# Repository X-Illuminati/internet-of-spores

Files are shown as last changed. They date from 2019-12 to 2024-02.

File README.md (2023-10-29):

# Internet of Spores
IOT Sensor Platform for ESP8266 Arduino
Specifically targeting Lolin D1 Mini.  
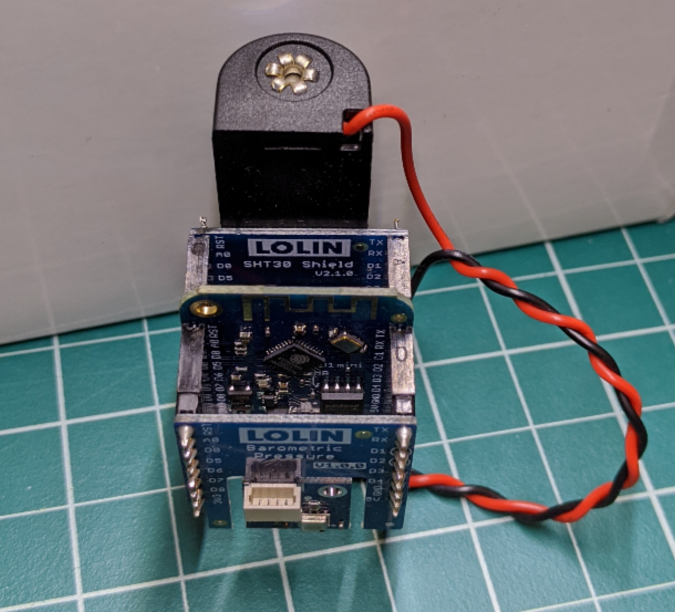
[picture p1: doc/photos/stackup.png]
D1 mini board stackup
  
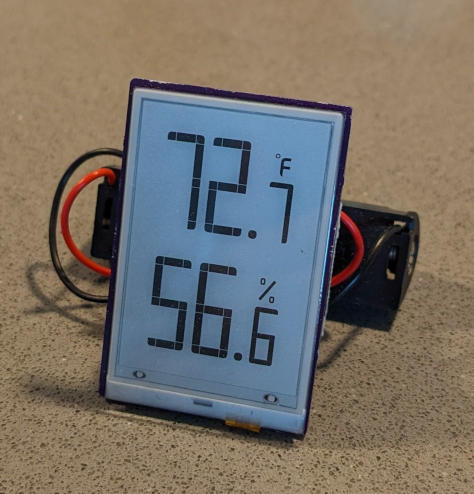
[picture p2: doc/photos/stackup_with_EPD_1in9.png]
Waveshare 1.9 in segmented E-Paper Display
  
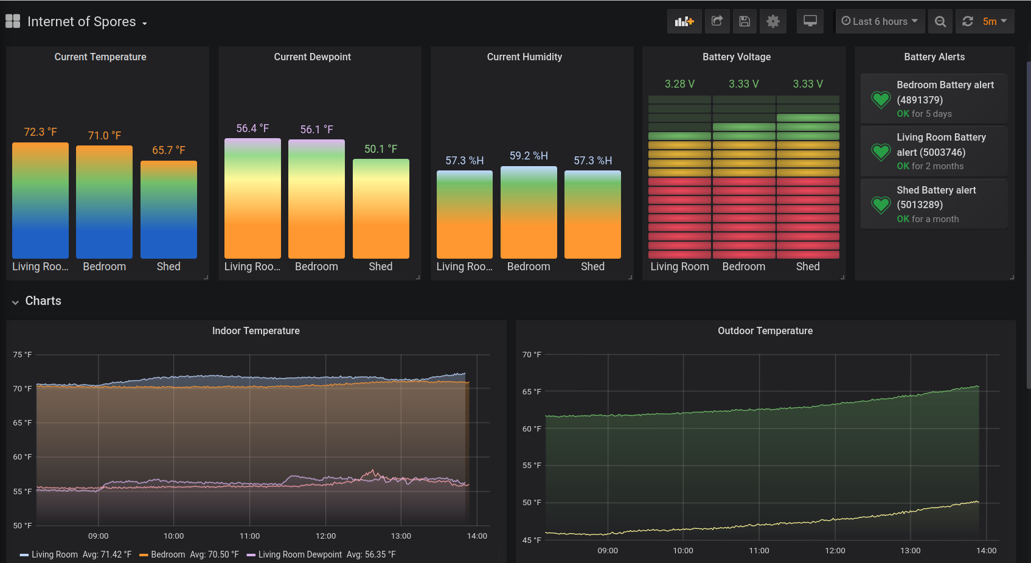
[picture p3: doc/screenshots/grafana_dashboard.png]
Grafana Dashboard


## Supported Sensors
* Temperature
  * SHT30
  * HP303B
* Relative Humidity
  * SHT30
* Barometric Pressure
  * HP303B
* Dust/Particle
  * PPD42NS

## Documentation (work-in-progress)
* [Developer Documentation](doc/README.md)
* [User Guide](doc/user_guide.md)

## Toolchain Setup and Library Dependencies

### ESP8266 Arduino
The ESP8266 Arduino toolchain is used to compile the code and provide basic
networking and multitasking services.
Project github: https://github.com/esp8266/Arduino

The toolchain can be installed via the Arduino board manager.
Instructions for this can be found [in their readme](https://github.com/esp8266/Arduino/blob/master/README.md).

#### Supported Version
I have thoroughly tested version 2.5.2 and 2.6.3. The latest version 3.0.2
required some changes to the code and I have not done the same level of testing
on these changes.
See the details below related to configurations/setting differences needed for
each version.

#### Board Setup
Most board settings can be left at their defaults.
* Don't forget to select your board type and COM port
* Need to configure some flash for SPIFFS
  * v2.5.2: select Flash Size "4M (1M SPIFFS)"
  * v2.6.3: select Flash Size "4MB (FS:1MB OTA:~1019KB)"
  * v3.0.2: select Flash Size "4MB (FS:1MB OTA:~1019KB)"

### WiFi Manager
There is a library dependency on WiFiManager by tzapu.
Project github: https://github.com/tzapu/WiFiManager

This can be installed via the library manager.
Please select a compatible version:
* v2.5.2: use WiFiManager version 0.14.0
* v2.6.3: use WiFiManager version 0.15.0-beta
* v3.0.2: use WiFiManager version 0.16.0

### Lolin HP303B Driver
There is a library dependency on the Lolin HP303B driver.
Project github: https://github.com/wemos/LOLIN_HP303B_Library

This is not available in the library manager so it will have to be installed
manually. Clone or download the library from the link above. Installation
instructions can be found [in this guide](https://www.arduino.cc/en/Guide/Libraries).

Tested version from commit 4deb5f.

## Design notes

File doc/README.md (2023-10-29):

# Documentation

## Table of Contents
* [System Architecture](system_architecture.md)
* Sensor Design
  * [Sensor Hardware](sensor_hardware.md)
  * [Sensor Software Architecture](software_architecture.md)
  * [Sensor Software Design](software_design_detail.md)
* Server Design
  * [Server Software Architecture](server_architecture.md)
  * [Server Software Design](server_design_detail.md)
* [User Guide](user_guide.md)

## Folder Structure
* [Top Level](../)
  * [README](../README.md)
  * [LICENSE](../LICENSE)
  * [internet_of_spores.ino](../internet_of_spores.ino) - Arduino Project File
  * C++ Modules for the Sensor Software
  * [flash.sh](../flash.sh) - Script to help program the ESP8266 over a serial port
  * [monitor.sh](../monitor.sh) - Script to monitor the ESP8266 serial port for debugging
  * [doc/](../doc/) - Documentation for the project
    * [README.md](README.md) - Documentation overview
    * [user_guide.md](user_guide.md) - Usage instructions
    * [drawio/](drawio/) - Draw.io Diagram Files
    * [photos/](photos/)
    * [renders/](renders/)
    * [screenshots/](screenshots/)
  * [firmware/](../firmware/) - Firmware images for the sensor nodes
    * ...-iotsp-tethered.bin - Firmware image for USB powered sensor nodes
    * ...-iotsp-battery.bin - Firmware image for battery-powered sensor nodes
    * ...-vcc-calibration.bin - Firmware image that rapidly reports battery level for calibration purposes
  * [kicad/](../kicad/) - KiCad projects
    * [EPD_1in9/](../kicad/EPD_1in9/) - KiCad project for the E-Paper Display Board
      * [EPD_1in9_schematic.pdf](../kicad/EPD_1in9/EPD_1in9_schematic.pdf) - PDF version of the schematic
  * [node-red/](../node-red/) - Node-Red flows and helper scripts
  * [openscad/](../openscad/) - OpenSCAD projects
    * [EPD_1in9.scad](../openscad/EPD_1in9.scad) - 3D Model for the Waveshare 1.9" E-Paper Display

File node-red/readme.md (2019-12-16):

# Node-RED flows.json
The node-red flows.json implements the measurement data collection and firmware
update procedure.

## Dependencies
The node-red flows are tested on v1.0.2 of Node-RED running on Node.js v10.15.2.
The node-red flows write data into an influxdb database. This has been tested
with v1.6.4 of influxdb-server.
Influxdb needs to be set up with a database called "home" and a measurement
called "internet_of_spores". The flows will look for this on localhost:8086.

There are some dependencies on community-contributed node programs.
These are available through the node-red palette manager and more details can
be found on [nodered.org](https://nodered.org).
The version numbers are the versions I have tested. Presumably newer versions
will also work.

* [node-red-contrib-readdir v1.0.1](https://flows.nodered.org/node/node-red-contrib-readdir)
* [node-red-contrib-md5 v1.0.4](https://flows.nodered.org/node/node-red-contrib-md5)
* [node-red-contrib-influxdb v0.4.0](https://flows.nodered.org/node/node-red-contrib-influxdb)

# Node-Red systemd unit file
The node-red.service is a systemd unit file that can be used to create a
systemd service to start and run the flows. It is compatible with being run as
a systemd user-service if installed in ~/.local/share/systemd/user/.

```shell
systemctl --user start node-red.service
systemctl --user restart node-red.service
systemctl --user stop node-red.service
systemctl --user status node-red.service
```

## State of Health Monitor
The soh-monitor.sh script will monitor the journal output of node-red and
expect periodic watch-dog statements. If node-red locks-up, the script will
restart it after a few minutes using systemctl.

The soh-monitor also has a systemd unit file, "node-red-soh.service". It can
be installed and started in the same way as node-red.service. Since it depends
on node-red.service, you only need to start the node-red-soh service and the
node-red service will automatically be started.

```shell
systemctl --user start node-red-soh.service
systemctl --user stop node-red-soh.service
systemctl --user status node-red-soh.service
```

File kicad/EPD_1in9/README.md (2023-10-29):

# EPD_1in9 KiCad

## KiCad 3D-view Render
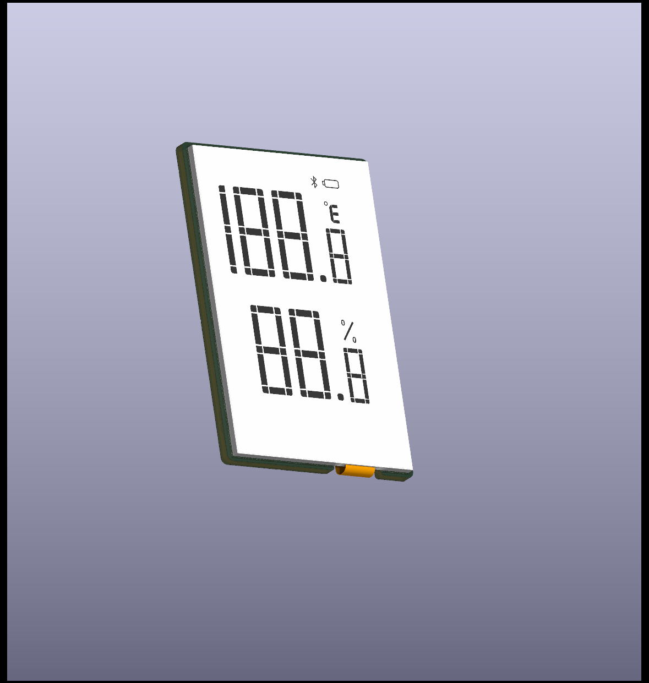
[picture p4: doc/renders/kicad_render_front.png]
KiCad 3D-view Render Front

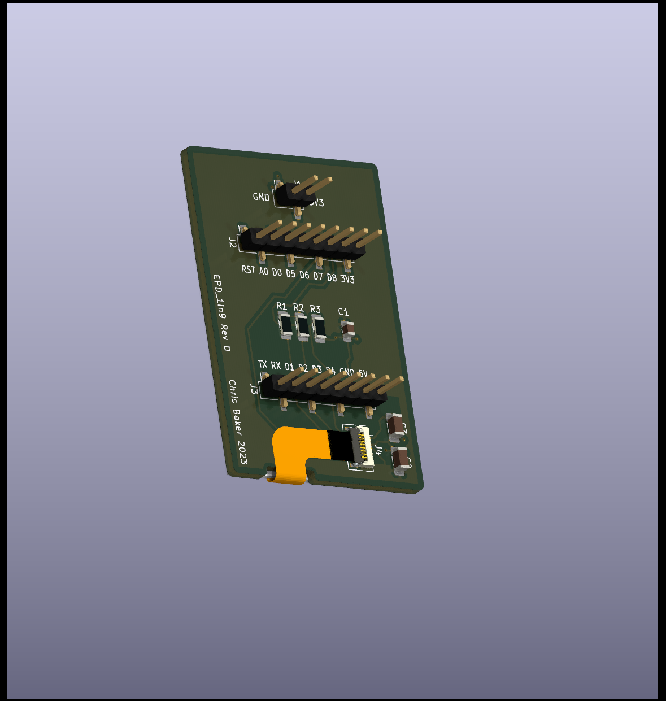
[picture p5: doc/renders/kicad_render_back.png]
KiCad 3D-view Render Back


## Schematic PDF
[EPD_1in9 Schematic](EPD_1in9_schematic.pdf)

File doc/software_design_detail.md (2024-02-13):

# Sensor Software Design
This outline is currently a work-in-progress.

## Table of Contents

* [Module Overview](#module-overview)
* [Project Configuration](#project-configuration)
* [Module Description](#module-description)
  - [Main Module](#main-module)
  - [RTC Mem](#rtc-mem)
  - [Persistent Storage](#persistent-storage)
  - [Connectivity](#connectivity)
  - [Sensors](#sensors)
  - [SHT30](#sht30)
  - [PPD42 Pulse Driver](#ppd42-pulse-driver)
  - [E-Paper Display Driver](#e-paper-display-driver)
* [Debugging and Unit Testing](#debugging-and-unit-testing)
  - [Development Mode](#development-mode)
  - [VCC Cal Mode](#vcc-cal-mode)
* [Future Improvements](#future-improvements)

---

## Module Overview

Refer to the [sensor software architecture](software_architecture.md) for an
overview of the component decomposition and logical architecture of the product.
The block diagram, repeated here, can serve as a high-level reference:  
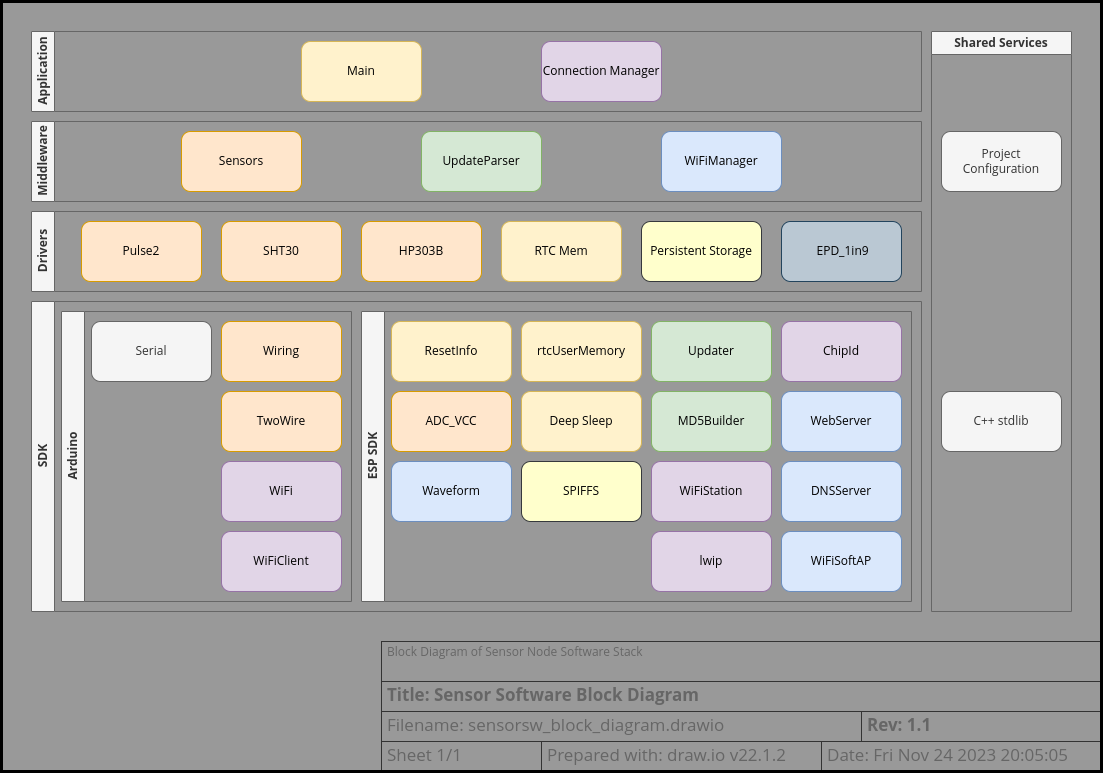
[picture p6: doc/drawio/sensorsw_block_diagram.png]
Software Stack


In this overview, the correspondence between the logical architecture and the
individual software modules is indicated by the dashed-line regions.  
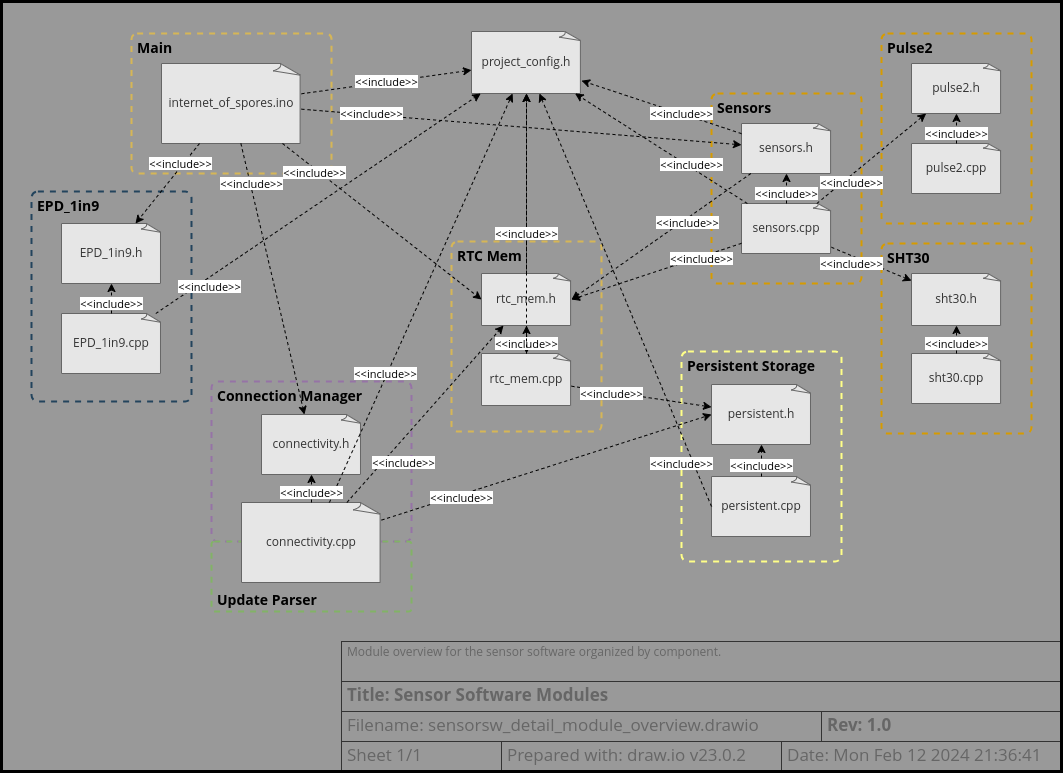
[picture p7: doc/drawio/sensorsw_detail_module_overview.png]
Module Overview
  
Later in the document, a detailed discussion of each module will be provided.

A couple of points are immediately apparent from examination of this diagram:
* project_config.h is a centralized locus of configuration information
* The RTC Mem component is more highly coupled than it should be
* connectivity.cpp is implementing two logical components

The later two points will be addressed in the
[future improvements section](#future-improvements).

---

## Project Configuration
- Describe configuration options, static modes, build ID
- Describe build system/toolchain

---

## Module Description
(configuration options, flow charts, classes, fault tolerance, notes, dependencies)
### Main Module
### RTC Mem
### Persistent Storage
### Connectivity
### Sensors
### SHT30
### PPD42 Pulse Driver
### E-Paper Display Driver

---

## Debugging and Unit Testing
### Development Mode
### VCC Cal Mode

---

## Future Improvements

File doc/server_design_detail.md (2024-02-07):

# Server Software Design

## Table of Contents

* [Module Overview](#module-overview)
* [Project Configuration](#project-configuration)
* [Module Description](#module-description)
  - [Node-RED Flows](#node-red-flows)
    + [Main Entry](#main-entry)
    + [Handle Sensor Readings](#handle-sensor-readings)
    + [Update Firmware](#update-firmware)
    + [Update Config](#update-config)
    + [State of Health](#state-of-health)
  - [Node-RED SOH Monitor](#node-red-soh-monitor)
    + [script_main](#script_main)
    + [monitor](#monitor)
    + [Signal Traps](#signal-traps)
* [Debugging and Unit Testing](#debugging-and-unit-testing)
  - [Debugging Node-RED](#debugging-node-red)
  - [Debugging Node-RED SOH Monitor](#debugging-node-red-soh-monitor)
* [Future Improvements](#future-improvements)

---

## Module Overview

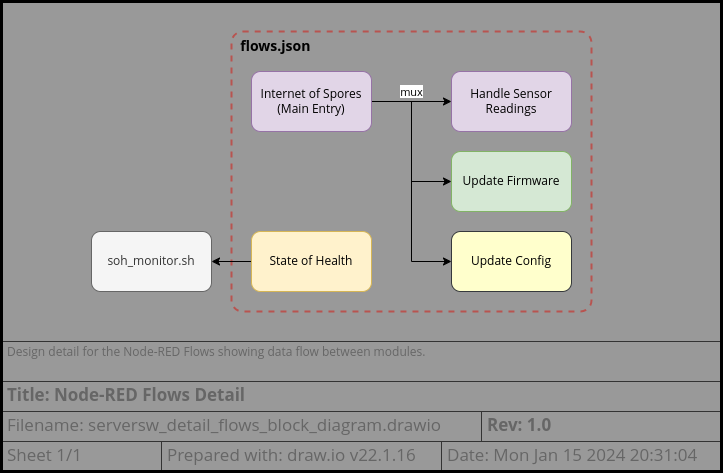
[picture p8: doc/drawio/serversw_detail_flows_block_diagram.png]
Module Data Flow Diagram
  
The server software components are split into [Node-RED Flows](#node-red-flows)
and the [SOH monitor](#node-red-soh-monitor). The flows.json includes several
sub-flows (arranged on different tabs in the UI).  
Based on the command in the incoming packet, the [Main Entry](#main-entry)
handler will hand it off to the relevant sub-flow. The
[State of Health](#state-of-health) sub-flow executes periodically and is
monitored by the external [SOH Monitor](#node-red-soh-monitor) utility.

---

## Project Configuration

The content of this component are all interpreted scripts and no compilation
step is needed. See the [software architecture](server_architecture.md) for more
details.

Launching of the Node-RED server and SOH Monitor is performed at startup by
[systemd unit files](https://www.freedesktop.org/software/systemd/man/systemd.unit.html).
To some extent these are configurable, but the
[soh-monitor.sh](../node-red/soh-monitor.sh) script is currently expecting the
units to be run under the "user" service manager. This behavior should be made
more configurable. Likewise, the script expects to be communicating with
systemctl and journalctl. In order to support other init systems, these commands
should be made more easily configurable.

For reference the unit files are:
* [node-red.service](../node-red/node-red.service) - starts the Node-RED server
* [node-red-soh.service](../node-red/node-red-soh.service) - starts the SOH
  monitor script

---

## Module Description

### Node-RED Flows

The flows are found in [flows.json](../node-red/flows.json) and are split into
the following tabs:
+ [Main Entry](#main-entry)
+ [Handle Sensor Readings](#handle-sensor-readings)
+ [Update Firmware](#update-firmware)
+ [Update Config](#update-config)
+ [State of Health](#state-of-health)

#### Main Entry

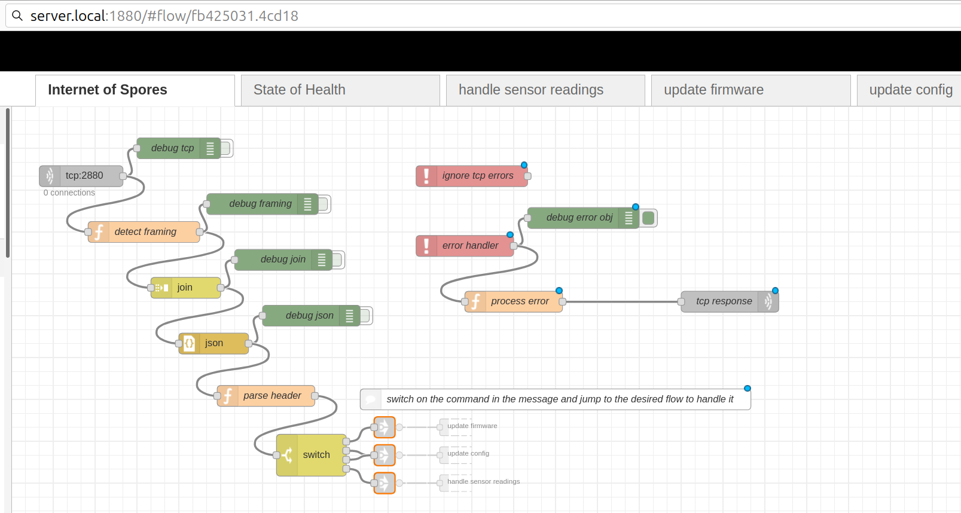
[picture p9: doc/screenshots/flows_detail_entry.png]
Flow Screenshot
  
The main flows listen on TCP port 2880 for incoming connections, collect
together fragmented packets, parse the packet as json, filter out the header
fields, and then pass the message on to the appropriate sub-flow based on the
command field.

The function nodes are relatively straightforward:
* "detect framing" looks for a null terminator in order to set the msg.complete
  flag
* "parse header" simply pulls out header fields from msg.payload and places them
  directly in the msg object
  - version
  - timestamp
  - node
  - firmware
* "process error" provides a TCP response of "error\0" for any error (except
  errors that it triggered with its own response)

The switch node works in the following way:
* If command == "update", transfers msg to the
  [update firmware sub-flow](#update-firmware)
* If command == "get_config" or "delete_config", transfers msg to the 
  [update config sub-flow](#update-config)
* If command is null, transfers msg to the
  [handle sensor readings sub-flow](#handle-sensor-readings)

#### Handle Sensor Readings

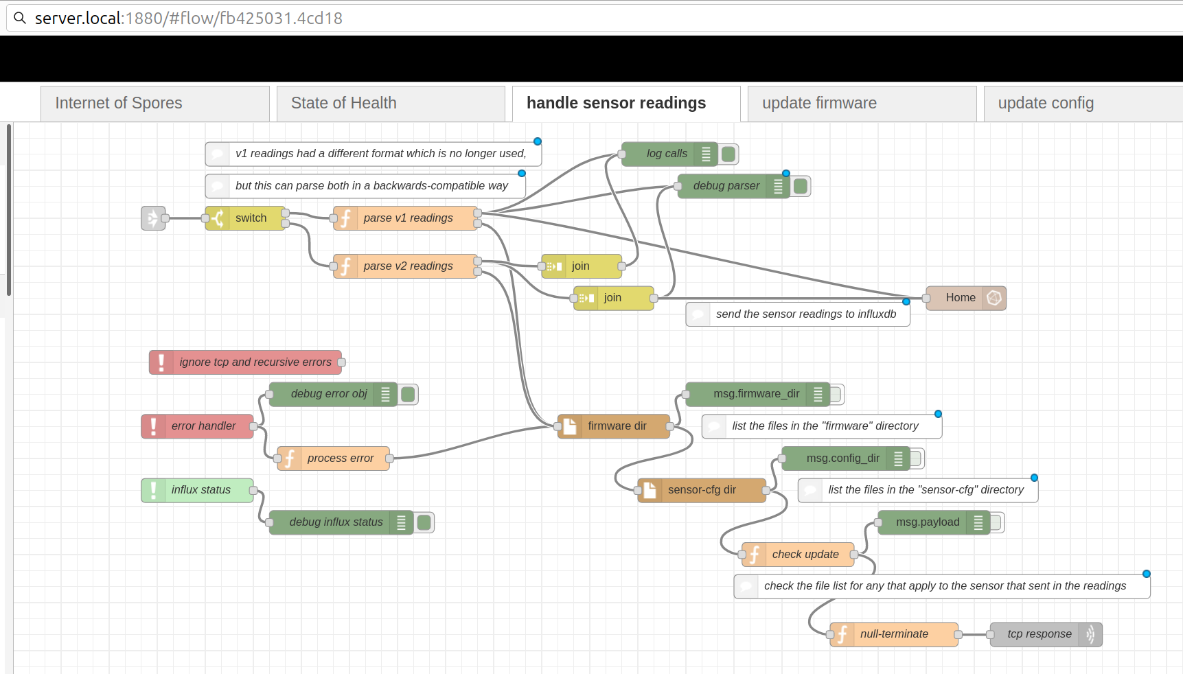
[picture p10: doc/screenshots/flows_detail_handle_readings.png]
Flow Screenshot


> 🪧 Note: this flow depends on the additional plugin modules:
> * [node-red-contrib-influxdb](https://flows.nodered.org/node/node-red-contrib-influxdb)
> * [node-red-contrib-readdir](https://flows.nodered.org/node/node-red-contrib-readdir)

When the msg is transferred to this sub-flow, it is first parsed to pull out the
sensor measurements. These measurements are then joined into a batch update to
be provided to the influxdb node.  
After each measurement is parsed, the response is generated - normally "OK". If
firmware updates or configuration updates are available, these flags will be
appended to the response.

The "influx status" node simply monitors status of the influxdb node and logs it
in the debug window.

**parse v2 readings**

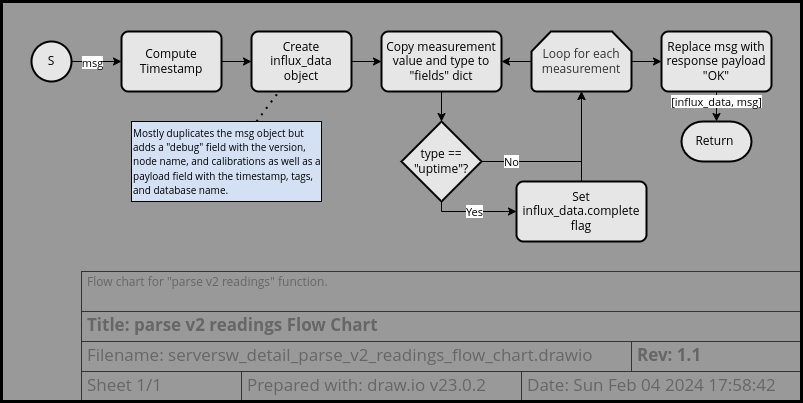
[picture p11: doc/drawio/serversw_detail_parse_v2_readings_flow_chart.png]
parse v2 readings flow chart


**check update**

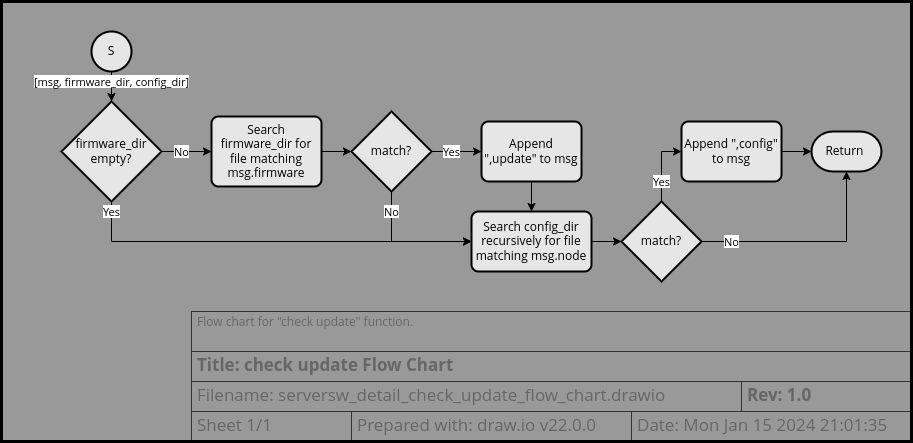
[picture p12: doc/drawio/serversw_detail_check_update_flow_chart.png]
check update flow chart


This function takes additionally as input msg.firmware_dir and msg.config_dir
which are provided by the preceding directory nodes.  These nodes can be
configured to modify the location of the respective firmware and sensor-cfg
directories, though it is probably easier to create softlinks in your Node-RED
runtime directory.

**null-terminate**

This function simply appends a "\0" character to the end of the response
message.

**process error**

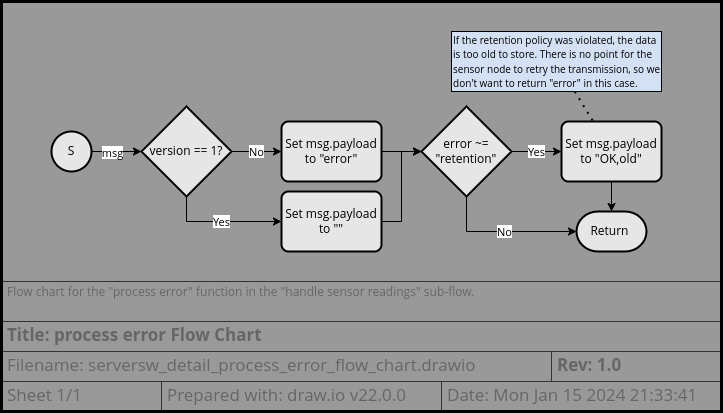
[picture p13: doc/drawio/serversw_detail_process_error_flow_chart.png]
process error flow chart


As on the main tab, the "process error" function returns a basic error response
to the sensor node in case any error occurs. Likewise, it ignores errors
generated by the "tcp response" node as these would likely generate further
errors as we attempt to send the error response recursively.

The difference from the main tab is that this function also handles errors from
the influx node and we want to handle "retention" errors as though they were
successful.  
The retention error indicates that InfluxDB received the measurement correctly,
but isn't storing it because it violates the retention policy. Generally, this
means that the timestamp is too old. In this case, there is no point for the
sensor node to retransmit the measurement, so we send an "OK,old" response.

#### Update Firmware

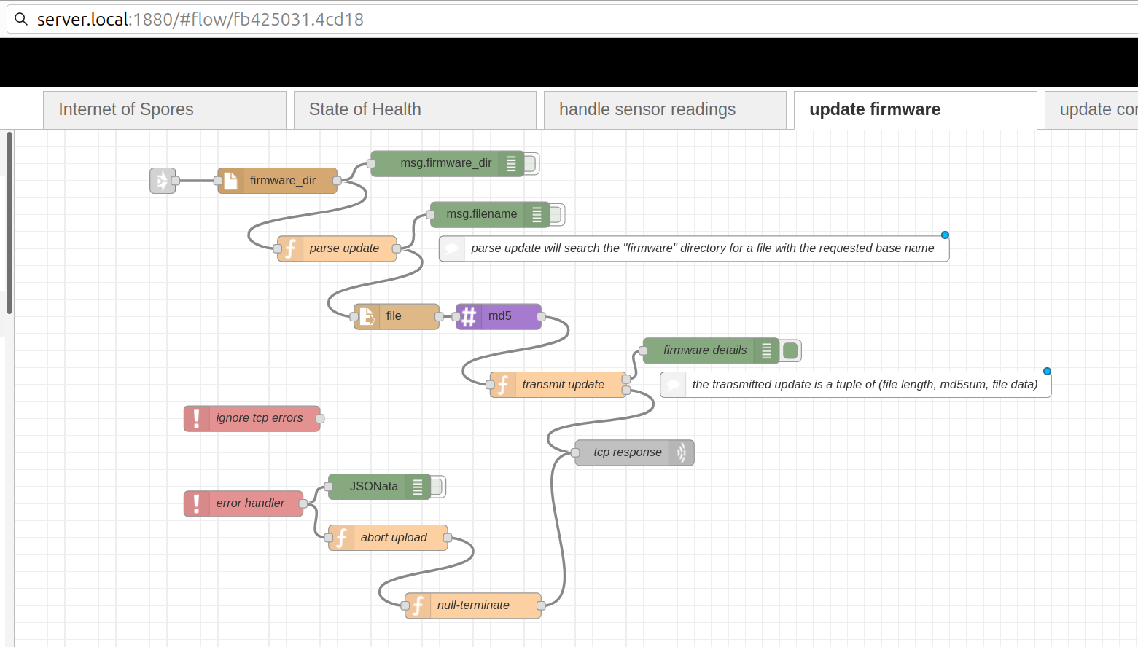
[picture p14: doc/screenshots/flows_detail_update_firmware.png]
Flow Screenshot


> 🪧 Note: this flow depends on the additional plugin modules:
> * [node-red-contrib-readdir](https://flows.nodered.org/node/node-red-contrib-readdir)
> * [node-red-contrib-md5](https://flows.nodered.org/node/node-red-contrib-md5)

When the msg is transferred to this sub-flow, the filename is extracted from the
payload argument and used to find the matching firmware image in the "firmware"
directory.  
If the image file is found, its md5 hash will be calculated and the update
package (length, md5, data) transmitted in the response.

**parse update**

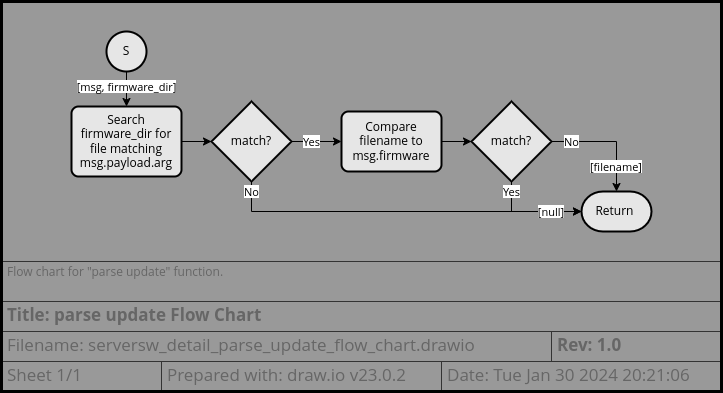
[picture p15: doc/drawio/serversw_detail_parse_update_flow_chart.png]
parse update flow chart


This function searches the list of files provided by the "firmware_dir" node
to find any that match the filename provided.  
As an extra check, it will ignore any firmware file that already matches the
firmware "fingerprint" reported by the sensor node as there is no point sending
an update file if the sensor is already running that version of software.

**transmit update**

This function crafts a response octet-string by concatenating the metadata and
content of the file:
* file length
* "\n"
* md5sum
* "\n"
* file data

> 🪧 Note: a final "\n" or "\0" is not included in this message as the file data
> will be processed by the ESP SDK firmware update functionality which expects
> a simple IO Stream with the file data only.  
> Additional framing would disturb the md5 checksum calculation.

**process error**

This function provides a TCP response of "0\n" for any error (except errors that
it triggered with its own response). 

**null-terminate**

This function simply appends a "\0" character to the end of the response
message.

#### Update Config

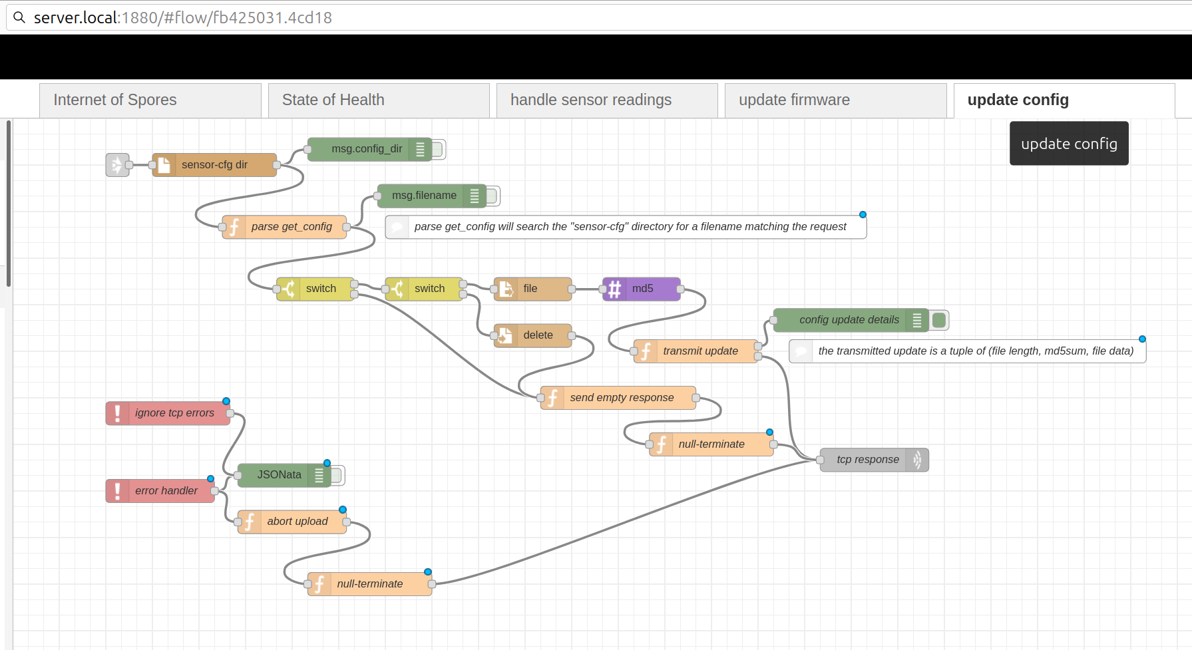
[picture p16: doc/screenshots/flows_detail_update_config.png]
Flow Screenshot


> 🪧 Note: this flow depends on the additional plugin modules:
> * [node-red-contrib-readdir](https://flows.nodered.org/node/node-red-contrib-readdir)
> * [node-red-contrib-md5](https://flows.nodered.org/node/node-red-contrib-md5)

When the msg is transferred to this sub-flow, the filename is extracted from the
payload argument and used to find the matching configuration file in the
"sensor-cfg" directory.  
Depending on whether the command is "get_config" or "delete_config", the file
will be returned to the sensor node or deleted, respectively.

**parse get_config**

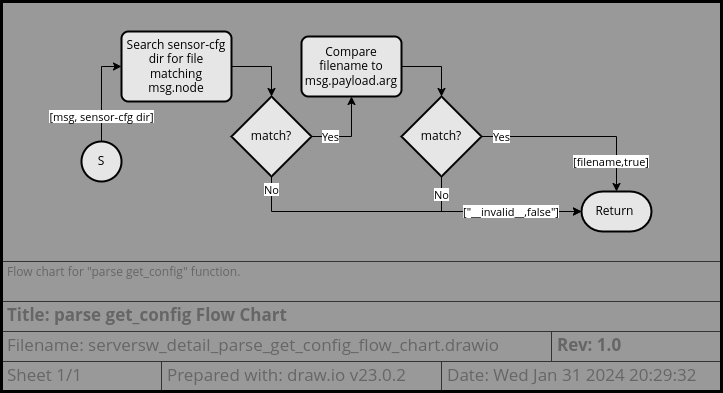
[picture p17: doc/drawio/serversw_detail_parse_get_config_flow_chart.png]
parse update flow chart


This function searches the list of files provided by the "firmware-cfg dir" node
to find any that match the node name and filename provided. For example, the
configuration update files might be in organized in subdirectories by node name
(sensor-cfg/node_name/cfg_file), but other schemes are possible
(sensor-cfg/node_name-cfg_file).

**transmit update**

This function crafts a response octet-string by concatenating the metadata and
content of the file:
* file length
* "\n"
* md5sum
* "\n"
* file data

**send empty response**

This function provides a TCP response of "\n" if no matching file was found.

**abort upload**

This function provides a TCP response of "0\n" for any error (except errors that
it triggered with its own response). 

**null-terminate**

This function simply appends a "\0" character to the end of the response
message.

#### State of Health

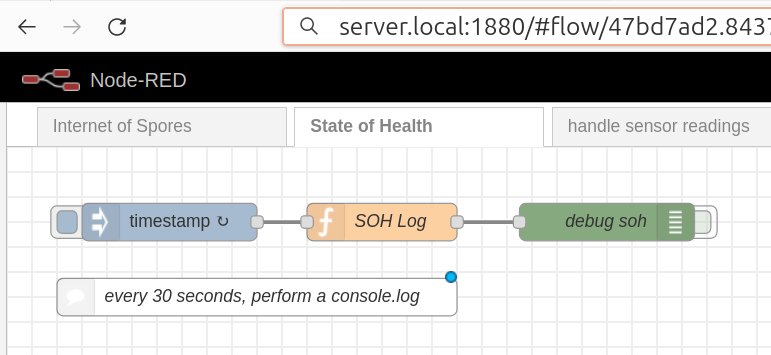
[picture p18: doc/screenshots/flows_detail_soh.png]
Flow Screenshot


This flow executes asynchronously every 30 seconds (starting 3 seconds after the
flows are started).

**SOH Log**

This function performs a console.log of the string "@SOH report@" + the
timestamp.

### Node-red SOH Monitor

The SOH Monitor script is located in
[soh-monitor.sh](../node-red/soh-monitor.sh).

The main configuration interface is via command line parameters.
These are optional:
* If 1 parameter is supplied, it is: timeout
* If 2 parameters are supplied: timeout, action count
* If 3 parameters are supplied: timeout, action count, max errors

The defaults for these (along with the additional RELOAD_TIME parameter) can be
adjusted at the top of the script.

This script depends on bash -- simpler bourne shells will probably fail in an
unexpected way. Additionally, it depends on systemd utilities: systemctl and
journalctl.

> 🪧 Note: The script expects Node-RED to be running under the "user" service
> manager rather than the "system" service manager. This should probably be
> made more configurable or allow some level of auto-detection.

There are 3 basic parts to the script:
* [Signal Traps](#signal-traps)
* [script_main](#script_main)
* [monitor](#monitor)

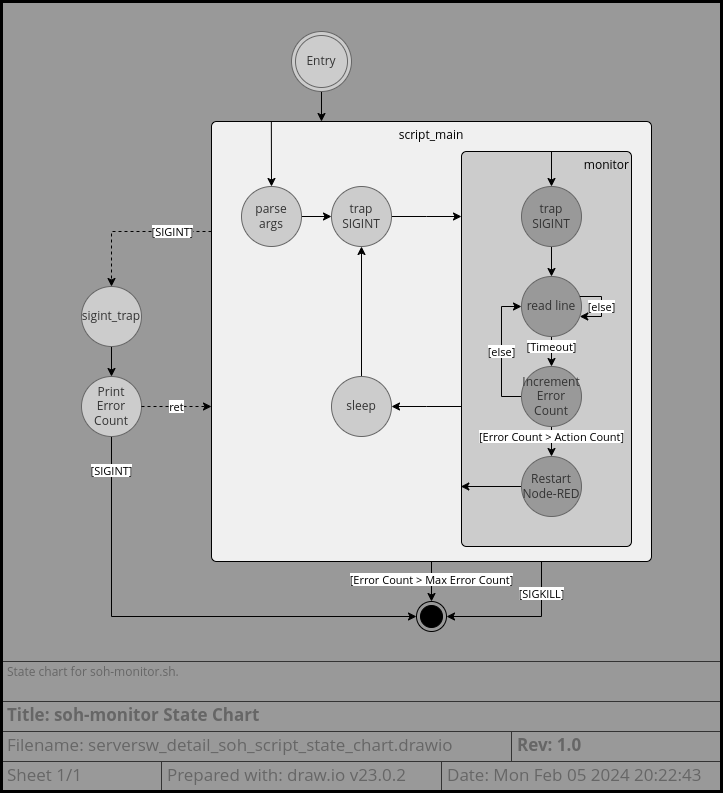
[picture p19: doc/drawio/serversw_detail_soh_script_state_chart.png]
soh-monitor State Chart


#### script_main

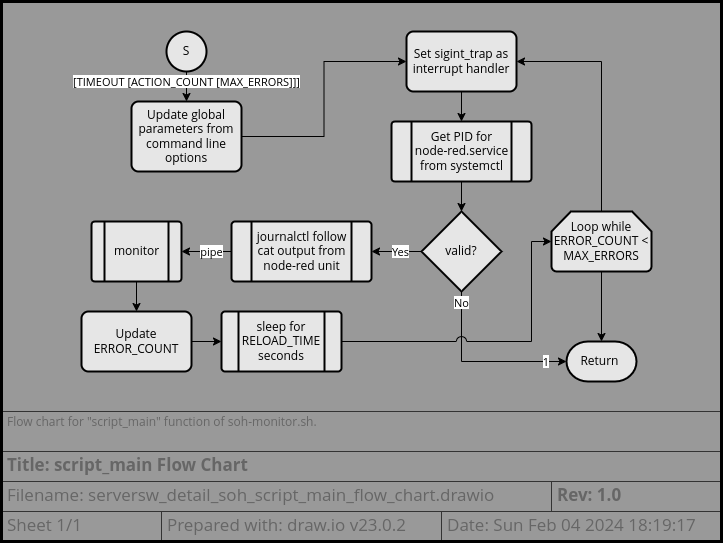
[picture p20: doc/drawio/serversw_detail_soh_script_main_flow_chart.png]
script_main flow chart


The `script_main` function parses the command line parameters, which allow overriding the default values of several parameters (as mentioned above).

It then sets up a trap for the interrupt signal and gets the process ID of the
Node-RED Server from systemd.

After that it executes `journalctl` in follow mode, filtering on the node-red
unit and outputting only the message content (cat mode). This output is piped
into the `monitor` function.  
The `monitor` function will only return if the maximum error count is exceeded,
if the input file descriptor (from `journalctl`) is closed, or if it took action
to restart the Node-RED service.  
When it returns, the return value will be the updated error count.

Assuming the max error count is not exceeded, `script_main` will wait for a few
seconds to let Node-RED finish restarting and then it will loop to the beginning
and get the new PID, start `journalctl` and pipe it into `monitor`, etc.

Most parameters are configurable on the command line, except for `RELOAD_TIME`,
which is the time that the script waits for the Node-RED service to restart.  
This is merely an oversight. For now, if you wish to modify this parameter, you
will just have to edit the [soh-monitor.sh](../node-red/soh-monitor.sh) script.

#### monitor

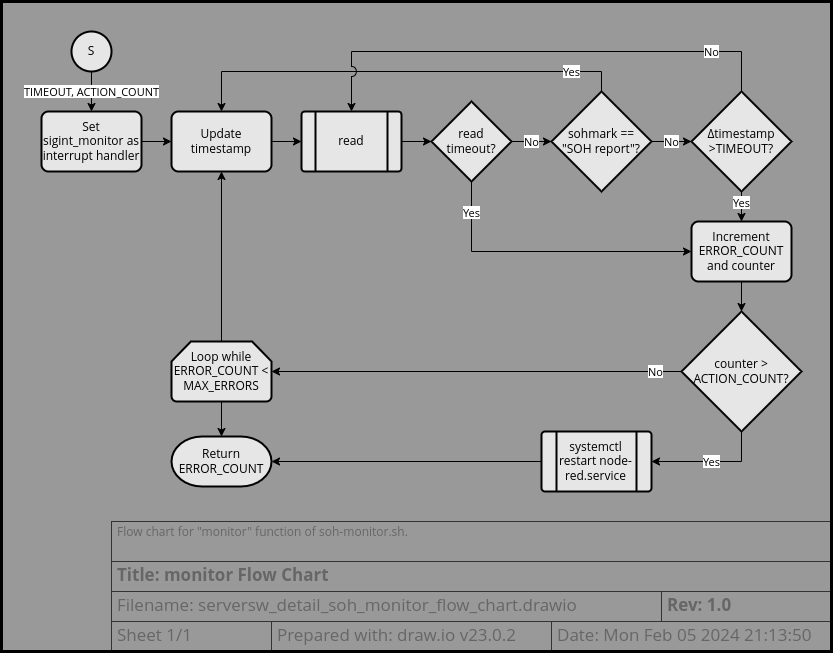
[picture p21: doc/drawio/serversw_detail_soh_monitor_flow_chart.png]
monitor flow chart


The `monitor` function reads lines from its standard input with a timeout. The
timeout is specified by the first argument to the function.  
The lines are parsed into fields delimited by '@'. The fields are `linehead`,
`sohmark`, and `sohtimestamp`. If `sohmark` matches "SOH report", then it is
considered to be a valid heartbeat. If the matching SOH mark is not found within
the timeout period, then the global `ERROR_COUNT` and a local `counter` will be
incremented.  
If the `counter` equals the action count (which is supplied as the second
input argument to the function), Node-RED will be restarted by invoking
`systemctl`. At this point the function will return.

**Return Value**

The function returns `ERROR_COUNT`.

**Error Handling**

If `ERROR_COUNT` exceeds the global `MAX_ERRORS`, the situation is deemed
suspicious and the function will return (and `script_main` will also return).

If the call to `read` fails with some other error code than timeout, the
function will return as the most likely cause is a broken pipe with
`journalctl`.

#### Signal Traps

The script traps SIGINT as a means of debugging.

`sigint_trap` is set as the handler for SIGINT while `script_main` is running.  
This trap will check whether you have sent an interrupt signal (via Ctrl-C)
twice within TIMEOUT seconds. The first interrupt will be ignored, but the
second interrupt within TIMEOUT seconds will cause the script to exit.  
When running the script on the command line, this allows testing of the
`sigint_monitor` behavior but also allows terminating the script easily by
pressing Ctrl-C a second time.

`sigint_monitor` is set as the handler for SIGINT while `monitor` is running.  
This trap will print the current value for ERROR_COUNT to standard output. This
can be helpful to periodically check whether any missed heartbeats are being
noticed.

Since `monitor` runs in a subshell, both handlers will trigger when running the
script from the command line. When executing the script from systemd, the
`sigint_trap` handler will be surpressed, but the `sigint_monitor` handler can
be triggered by using `kill` to send the INT signal directly to the subshell.

---

## Debugging and Unit Testing

The Node-RED flows and SOH monitor script don't have any unit tests.
😿

### Debugging Node-RED

There are several debug nodes throughout the Node-RED flows. Most of these are
disabled to avoid spam, but they can be re-enabled by clicking on the green
button next to them. You don't need to deploy the changes for this debug
enable/disable flag to take effect.  
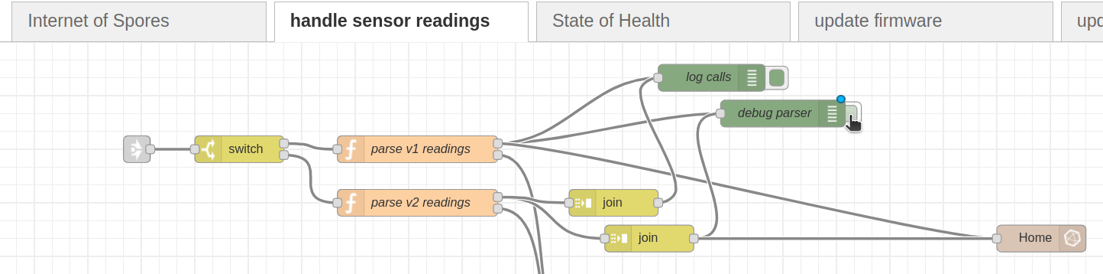
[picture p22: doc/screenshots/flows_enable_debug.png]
screenshot enable debug flag


By default the log output in Node-RED goes to the debug window on the side
panel:  
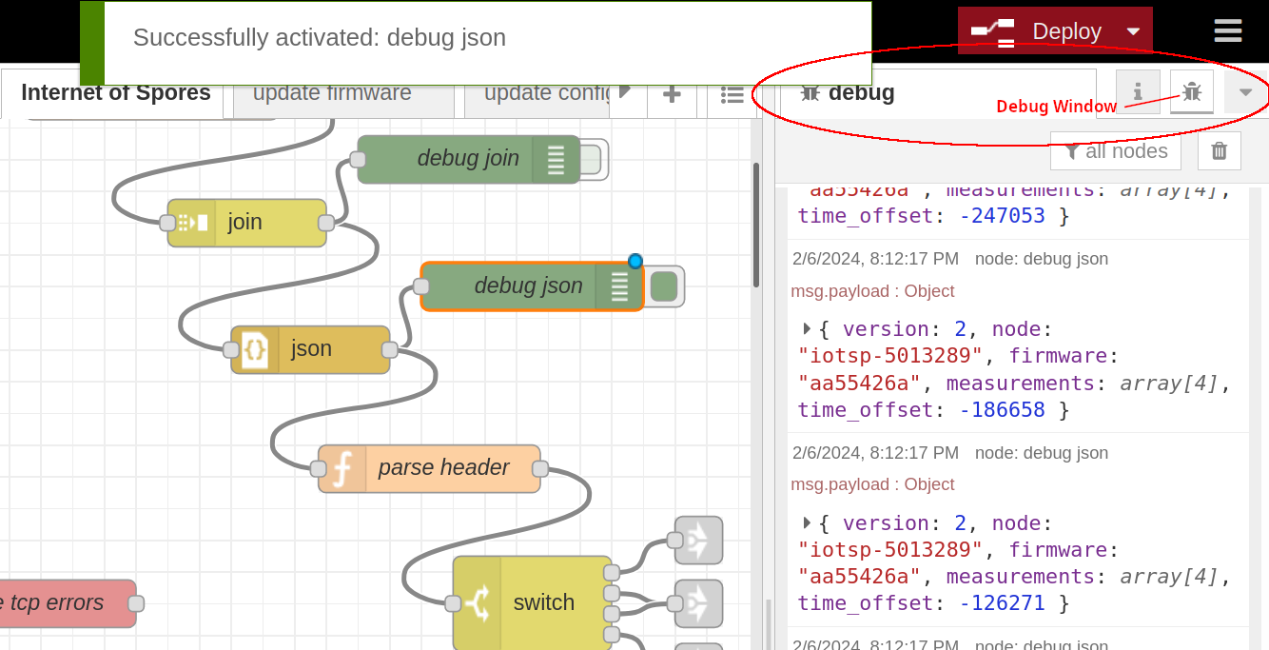
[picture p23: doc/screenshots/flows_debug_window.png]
screenshot debug window


You can redirect it to the system console by changing the properties of the
debug node (double click):  
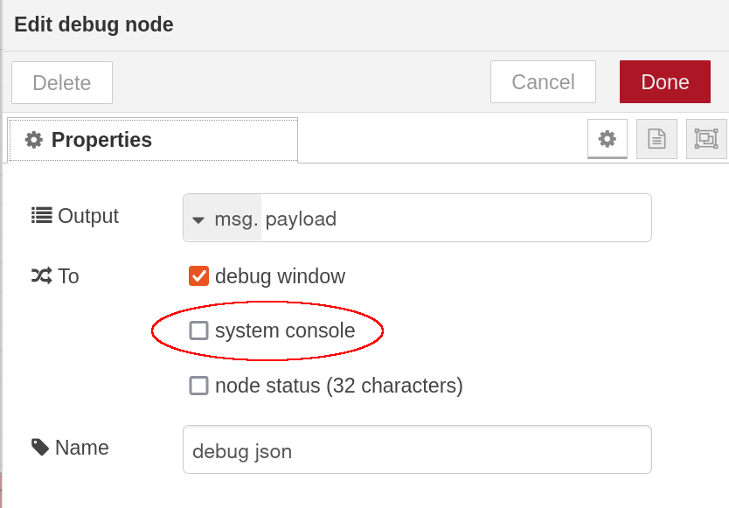
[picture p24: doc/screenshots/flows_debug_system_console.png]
screenshot debug node properties

> 🪧 Note: changes to these properties will not take effect until you deploy the
> flows.

Likewise, in any of the function nodes, you can call `console.log()` to send a
log message to the system console.

To monitor the system console, use `journalctl` to "follow" the log output:
```sh
journalctl --user --unit node-red.service -f
```

### Debugging Node-RED SOH Monitor

Check whether the Node-RED and Node-RED SOH service are running:
```sh
systemctl --user status node-red.service
systemctl --user status node-red-soh.service
```

You should see that these services are active (running).  
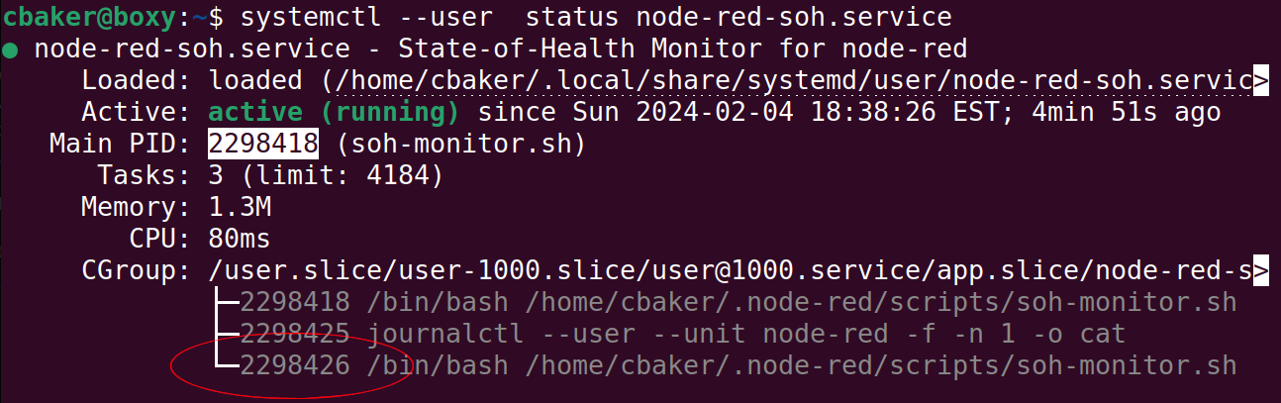
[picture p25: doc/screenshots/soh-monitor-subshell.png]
Subshell screenshot


Additionally, the last few lines of the journal output will be printed, so you
can check whether SOH report messages are being printed.q

If you send a SIGINT to the subshell running the monitor function, the script
will print out the number of heartbeat timeouts that it has caught so far. You
can find the PID of the subshell by checking the `systemctl` status for the
service as mentioned above.
```sh
kill -SIGINT <PID> #see example in screenshot above
journalctl --user --unit node-red-soh.service --lines 10
```

If you want to inject a fault condition, you can kill or suspend the Node-RED
server process:
```sh
systemctl --user status node-red.service    # get current PID
kill <Node-RED PID>   # use PID from above
journalctl --user --unit node-red-soh.service -f   # monitor response
```

Or you can briefly suspend the Node-RED server process to see the SOH failure
and recovery:
```sh
kill -STOP <Node-RED PID>
# wait a while to see SOH report failures in the soh-monitor journal
kill -CONT <Node-RED PID>
```

Additionally, you can run the soh-monitor script from the command line. This
will let you send Ctrl-C more easily to print the error count and monitor the
status without needing to use `journalctl`.
```sh
# stop the soh-monitor if it is running
systemctl --user stop node-red-soh.service
# restart node-red since it was dependent on node-red-soh
systemctl --user start node-red.service
# run the soh monitor
./soh-monitor.sh
```

---

## Future Improvements

**Node-RED Flows**

It would be good to find some way to make the tabs more modular so they can be
included into an existing set of flows or so they can be expanded upon but still
have an easy upgrade path.  
It seems like the import and export of "libraries" should make this possible.
Likewise, the use of "subflows" might offer a modular solution or at least make
the inclusion of the libraries more straightforward.

**Node-RED SOH Monitor**

It might be good to reduce the reliance on systemd in order to support other
init systems.  The availability of systemd services could likely be
auto-detected and, if not present, fallback on standard syslog monitoring and
"service" helper utilities.

Currently, the script hardcodes the `--user` parameter to systemctl and
journalctl. This should be made configurable or allow for some sort of
auto-detection mechanism.  
It seems like systemctl has enough introspection capabilities to allow for
auto-detection.

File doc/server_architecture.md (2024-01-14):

# Server Software Architecture

## Table of Contents

* [Overview and Block Diagram](#overview-and-block-diagram)
* [External Dependencies](#external-dependencies)
* [Component Description](#component-description)
  - [Packaged Applications](#packaged-applications)
    + [Node-RED](#node-red)
    + [InfluxDB](#influxdb)
    + [Grafana](#grafana)
  - [Project Applications](#project-applications)
    + [Node-RED Flows](#node-red-flows)
    + [Node-RED SOH Monitor](#node-red-soh-monitor)
* [Dynamic Behavior](#dynamic-behavior)
  - [Modes of Operation](#modes-of-operation)
  - [Process Request](#process-request)
  - [Node-RED SOH Behavior](#node-red-soh-behavior)
  - [Visualization](#visualization)
* [Cybersecurity](#cybersecurity)
  - [Node-RED Security](#node-red-security)
  - [InfluxDB Security](#influxdb-security)
  - [Grafana Security](#grafana-security)
  - [Node-RED Flows Security](#node-red-flows-security)
* [Error Handling](#error-handling)
  - [General Failures](#general-failures)
  - [Node-RED Server Failure](#node-red-server-failure)
  - [Node-RED Packet Handling](#node-red-packet-handling)

--------------------------------------------------------------------------------

## Overview and Block Diagram

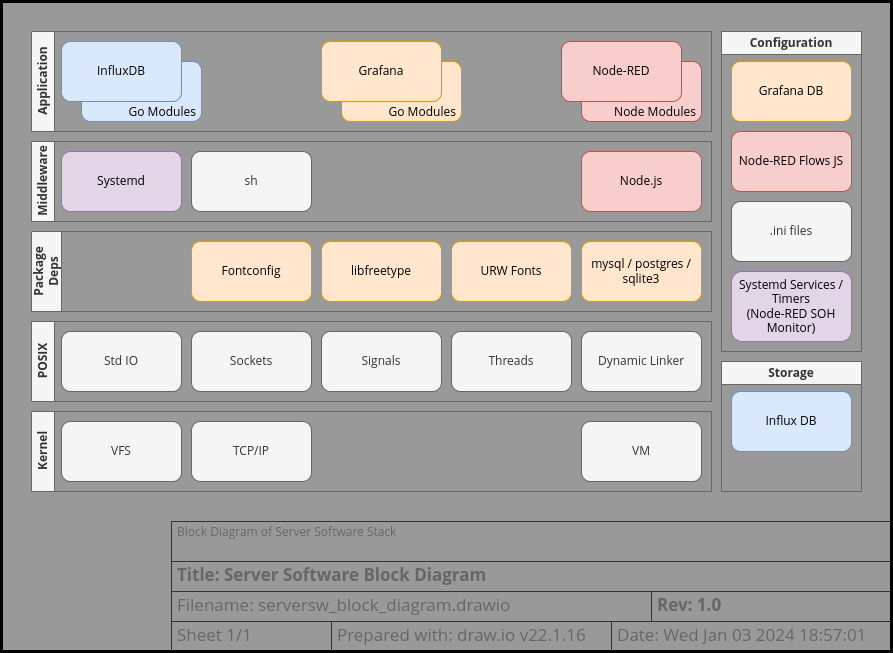
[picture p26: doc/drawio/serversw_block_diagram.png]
Server Software Block Diagram
  
The server software is the most loosely defined part of the system. It is mostly
based on packaged software that can be configured by the end-user. The version
of the components used and even the operating system are largely immaterial.
And, there is broad flexibility to split up the components across multiple
physical or virtual computers.  
The above diagram shows an example configuration with a Linux kernel and all
server components running on a single system. This might be a Raspberry PI SBC
(single board computer) or a rack server running Ubuntu Server edition. Many of
the components are available via Docker, further increasing flexibility of
deployment.

At a high level, the software stack can be broken down into "applications" and
"system services".  
As long as the packaged applications have their dependencies met, the underlying
system services are relatively unimportant.  
In the above diagram, the "middleware", "package deps", "POSIX" API, and
"Kernel" layers are all part of the system services. These will be described
briefly here and in the [External Dependencies](#external-dependencies) section,
but detailed information on these is out-of-scope for this documentation.

The "applications" will be discussed in some additional detail in this document
but won't be covered in the [detailed design](server_design_detail.md) document
as these are packaged applications that have their own design documentation.

Likewise, the "configuration" and "storage" aspects of the diagram will not be
discussed further since this is up to the end user. The exception is the
[Node-RED Flows](#node-red-flows) and
[Node-RED SOH Monitor](#node-red-soh-monitor) (which is implemented via systemd
timers). These are the main contribution of this project to the server
configuration and will be discussed in detail here and in the
[detailed design](server_design_detail.md) document.

All of these applications are POSIX-based and require suitable system services
provided by the C library and kernel to support their operation.  
The block diagram has standard POSIX services listed alongside typical kernel
services provided by the OS. These are likely an incomplete list on both counts
and are merely suggestive of a typical software stack for the server.  
To elaborate, slightly:
* Std IO - file and stream IO
* Sockets - [Berkeley socket](https://en.wikipedia.org/wiki/Berkeley_sockets)
  implementation
* Signals - POSIX process and exception signalling
* Threads - POSIX pthread implementation
* Dynamic Linker - C API to provide dynamic loading (e.g. dlopen, etc.) as well
  as a runtime dynamic linker provided by the OS (e.g. ld.so)
* VFS - Virtual File System (Linux-specific file system namespace and structure)
* TCP/IP - stack provided by the OS for TCP/IP communication
* VM - Virtual Memory provided by the OS (e.g. system calls like mmap as well as
  separation of process memory)

Ultimately, the organization of the server applications provides 3 functions
that are useful to the overall system:
1. Management Logic for the sensor nodes (provided by [Node-RED](#node-red))
2. Database for storing sensor readings (provided by [InfluxDB](#influxdb))
3. Display of sensor readings (completely optional, but discussed here as
   [Grafana](#grafana))

Since the interface between these components is TCP/IP, they can be freely
moved, upgraded, and, to some extent, replaced.

--------------------------------------------------------------------------------

## External Dependencies

__Packaged Applications__  
These packaged applications are provided by 3rd parties. It should be stressed
that the version specified is not so important and the latest version should
work correctly.

| External Dependency | Tested Version | Link
|---|---|---
| Node-RED | 0.20.7 | https://nodered.org/
| InfluxDB | 1.7.8 | https://www.influxdata.com/
| Grafana | 6.5.2 | https://grafana.com/

These are used essentially in their stock configuration with the exception of
Node-RED. The provided [Node-RED Flows](#node-red-flows) require a few
community-supplied plugins.

__Package Dependencies__  
On my system, Grafana has the following dependencies on additional packages:

| External Dependency | Notes
|---|---
| Bourne shell | e.g. bash
| Init Service | e.g. SysV init or systemd
| Fontconfig | http://fontconfig.org/
| FreeType library | https://freetype.org/
| urw-fonts | open fonts package

This list will obviously differ from one operating system distribution to
another and should automatically be resolved by the Grafana installer or system
package manager.

__Additional Dependencies__

_Grafana_  
Grafana requires a back-end database to store its configuration. This can be
provided via MySQL, PostgreSQL, or SQLite3 (which is the default).  
The selection is configured via the configuration .ini file and the appropriate
system library needs to be available via dlopen call.

Since Grafana is written in [Go](https://go.dev/), it has dependencies on many
additional Go Modules. These are provided alongside the application and,
generally, don't require explicit installation.

An option to install via docker appears to be available, but this option is
untested by the author of this document.

_InfluxDB_

Since InfluxDB is written in [Go](https://go.dev/), it has dependencies on many
additional Go Modules. These are provided alongside the application and,
generally, don't require explicit installation.

_Node-RED_  

Since Node-RED is written in [Node.js](https://nodejs.org/), it requires the
Node.js interpreter and npm utility to be installed on the system.

| External Dependency | Tested Version | Link
|---|---|---
| Node.js | 10.16.3 | https://nodejs.org/
| npm | 6.9.0 | https://www.npmjs.com/

Likewise, it has dependencies on many additional Node.js Modules. These should
be installed alongside the application automatically using the npm package
manager. It is suggested to follow the installation instructions on the
[nodered.org website](https://nodered.org/docs/getting-started/local).  
An option to install via docker or snap appears to be available, but these
options are untested by the author of this document.

__Additional Plugins__

The provided [Node-RED Flows](#node-red-flows) require a few community-supplied
plugins. These need to be installed through the Node-RED UI.  
Again, the specific version is probably not so important and the latest
version should work.

| Node-RED Plugin | Tested Version | Link
|---|---|---
| node-red-contrib-influxdb | 0.3.1 | https://flows.nodered.org/node/node-red-contrib-influxdb
| node-red-contrib-md5 | 1.0.4 | https://flows.nodered.org/node/node-red-contrib-md5
| node-red-contrib-readdir  | 1.0.1 | https://flows.nodered.org/node/node-red-contrib-readdir

Without these the provided Node-RED flows will not start.  
It may be possible to install these in an automated way (e.g. as part of your
docker script).

--------------------------------------------------------------------------------

## Component Description

### Packaged Applications

These 3rd-party applications come packaged for the OS (or container system) and
have their own external detailed documentation. However, they don't generally
have an architectural overview available as part of their public documentation,
so there will be some discussion of these aspects in the next few chapters.

#### Node-RED

##### Description

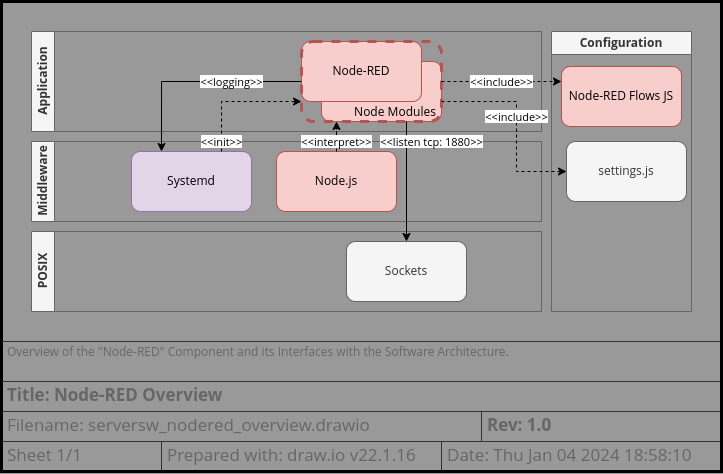
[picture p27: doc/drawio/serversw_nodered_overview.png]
Node-RED Overview
  
[Node-RED](https://nodered.org/) is a [Node.js](https://nodejs.org/) application
that provides a flow-based, visual-programming environment for creating the
glue-logic that connects the networked IOT sensors to the backend database.

Public documentation for Node-RED, including installation instructions and API
reference can be found on [the nodered.org website](https://nodered.org/docs/).

##### Dependencies

See [External Dependencies](#external-dependencies) for notes about the
dependencies on Node.js and the additional Node-RED plugins needed.  

##### Configuration

Configuration of this component is provided via the settings.js file in its
runtime directory.  
See the
[documentation](https://nodered.org/docs/user-guide/runtime/settings-file)
on the nodered.org site for more details.

Additionally, the flows that will be executed are loaded from the same
directory. The flows to work with the sensor nodes in this project are provided
in [flows.json](../node-red/flows.json). More details about these flows are
described [below](#node-red-flows).

##### Public API

The Node-RED server listens on TCP port 1880 (by default).  
On this port, it will provide a standard web (HTTP) interface for access via a
web browser. With this interface, it provides access to the flow editor and
debug console.  
Node-RED Screenshot

#### InfluxDB

##### Description

InfluxDB Overview  
[InfluxDB](https://www.influxdata.com/) is a time series database used to store
the sensor readings received from the sensor nodes.  
Public documentation for InfluxDB, including installation instructions and API
reference can be found on
[the influxdata.com website](https://docs.influxdata.com/influxdb/v2/).

The use of InfluxDB in this system can be replaced with a different database
storage backend if the [Node-RED Flows](#node-red-flows) are updated
accordingly.

##### Dependencies

InfluxDB is generally installed with all of the dependencies it needs.  
A POSIX-compatible C library is assumed.

##### Configuration

Configuration of this component is provided via the influxdb.conf file in the
associated config directory.  
See the [InfluxDB configuration options](https://docs.influxdata.com/influxdb/v2/reference/config-options/)
for more details.

##### Public API

The InfluxDB server listens on TCP port 8086 (by default).  
On this port, it will provide a REST API for database queries.
See the [API documentation](https://docs.influxdata.com/influxdb/v2/api-guide/)
on the influxdata.com website for more details.

The InfluxDB server also listens on TCP port 8088 for interfacing with other
InfluxDB controllers. This functionality is not used within this system.

#### Grafana

##### Description

Grafana Overview  
[Grafana](https://grafana.com/) is an interactive analytics and chart
visualization application which can be used to display the sensor data stored in
the [InfluxDB database](#influxdb).  
Public documentation for Grafana, including installation instructions can be
found on [the grafana.com website](https://grafana.com/oss/grafana/).

The use of Grafana in this system can be replaced with any suitable data
visualizer frontend that has support for InfluxDB.

##### Dependencies

See [External Dependencies](#external-dependencies) for notes about the
dependencies on system libraries and services. These will generally be resolved
by the installer or your package manager.

##### Configuration

Configuration of this component is provided via the grafana.ini file in the
associated config directory.  
See the [configuration options](https://grafana.com/docs/grafana/latest/setup-grafana/configure-grafana/)
for more details.

Additionally, the users of Grafana can create and configure dashboards according
to their needs. These are stored in a SQL database provided by a backend that is
configurable (sqlite by default).

##### Public API

The Grafana server listens on TCP port 3000 (by default).  
On this port, it will provide a standard web (HTTP) interface for access via a
web browser. With this interface, it provides access to the dashboards and data
source configuration  
Grafana Screenshot

### Project Applications

#### Node-RED Flows

##### Description

Node-RED Flows Overview  
The [Node-RED Flows](../node-red/flows.json) provide the glue logic for the
system. By running these flows in [Node-RED](#node-red), the server will listen
for incoming connections on TCP port 2880 (by default) and process the request
to perform one of 3 actions:
1. Process sensor readings and store them in the configured InfluxDB database
2. Transmit a firmware update file
3. Transmit a configuration update file

To store the sensor readings, the readings are processed (to calculate an
absolute timestamp) and the InfluxDB API is used to transmit the data to
[InfluxDB](#influxdb) on TCP port 8086.  
The readings are transmitted as a json string for easy processing within
Node-RED.  
If the readings are stored successfully, an "OK" string is sent back to the
sensor node; otherwise an "error" string is returned. If there are available
firmware or configuration updates for the sensor node, ",config" or ",update"
are appended to the response string.

Normal POSIX directory and file operations are used to find relevant firmware
and configuration update files.

There is an additional flow for logging a heartbeat message, related to the
[Node-RED SOH Monitor](#node-red-soh-monitor).

##### Dependencies

The flows depend on [Node-RED](#node-red) and the corresponding Node.js
installation to execute.  
Refer also to the "Additional Plugins" sub-section of
[External Dependencies](#external-dependencies) for information about some
additional Node-RED plugins that need to be installed manually before the flows
will start.

##### Configuration

There are 3 main aspects of the flows that may need to be configured:
1. The level of debug logging that is displayed
2. The TCP port to listen on for incoming connections
3. The details of the InfluxDB database

1:  
To enable additional debug logging, simply click the green button next to one of
the debug nodes. There is no need to "deploy" the flows unless you want the
change to the setting to be remembered permanently.  
Debug Level Modification Screenshot

> 🪧 Note: The debug messages from the debug nodes show up in the debug
> side-panel and not in the console output or systemd journal.
> To log messages to the console, the `console.log()` function must be used
> explicitly from a javascript function node.

2:  
The TCP port to listen on can be configured by modifying the TCP node on the
first page of flows.  
TCP Port Modification Screenshot

3:  
The InfluxDB database details can be configured by modifying the influx batch
node (labeled "Home") on the "handle sensor readings" page.  
InfluxDB Modification Screenshot

##### Public API

Interaction with the Node-RED Flows involves sending a json string via TCP port
2880.

There are 2 basic packet types for this API: measurements and commands.  
For measurement, a type field identifies the type of measurement that is being
transmitted. The final measurement packet has some additional fields.  
Commands request the server to perform some function. The possible commands are:
"get_config", "delete_config", and "update".

This is currently version 2 of the API. Version 1 is undocumented.

###### Measurements

Most measurement packets have this format:
```json
{
  "version":2,
  "node":String,         #name of the sensor node
  "firmware":String,     #firmware name/identifier (preinit_magic)
  "measurements":
    [                    #array of sensor readings
      {                  #sensor reading object
        "type":String,   #name for the type of sensor reading
                         #possible values types are:
                         # "unknown",
                         # "temperature",
                         # "humidity",
                         # "pressure",
                         # "particles 1.0µm",
                         # "particles 2.5µm",
                         # "battery"
        "value":Number
      },
      ...
    ],
  "time_offset":Number   #The age in ms of the measurement
                         #Note: this should be expressed as a negative number
}
```

The final measurement packet should include the "uptime" measurement to trigger
the bulk transfer to InfluxDB. It also includes the sensor calibrations for
debugging purposes.
```json
{
  "version":2,
  "node":String,         #name of the sensor node
  "firmware":String,     #firmware name/identifier (preinit_magic)
  "measurements":
    [                    #array of sensor readings
      {                  #sensor reading Object
        "type":String,   #name for the type of sensor reading
                         #possible strings for type are:
                         # "unknown",
                         # "temperature",
                         # "humidity",
                         # "pressure",
                         # "particles 1.0µm",
                         # "particles 2.5µm",
                         # "battery"
        "value":Number
      },
      ...
      {
        "type":"uptime",
        "value":Number   #sensor node uptime in seconds
      }
    ],
  "calibrations":
    [                    #array of calibration values
      {                  #calibration Object
        "type":String,   #name for the type of calibration
                         #possible strings for type are:
                         # "temperature",
                         # "humidity",
                         # "pressure",
                         # "battery"
        "value":Number
      },
      ...
    ],
  "time_offset":Number   #The age in ms of the measurement
                         #Note: this should be expressed as a negative number
}
```

After receiving each measurement, the server will respond with a simple string composed of a comma separated list of response flags.  
If the measurement was parsed properly, it will respond with "OK", otherwise it
will respond with "error".  
If there is a firmware update available, the server will include ",update" in
its response. If there is a configuration file update available, the server will
include ",config" in its response.  
Finally, the server's response will end with a newline character `\n`.

###### Commands

**get_config**  
The get_config command requests the server to send a configuration update to the
sensor node.

```json
{
  "version":2,
  "node":String,          #name of the sensor node
  "firmware":String,      #firmware name/identifier (preinit_magic)
  "command":"get_config",
  "arg":String            #the filename requested
                          #possible strings for the filename arg are:
                          # "node_name",
                          # "report_host_name",
                          # "report_host_port",
                          # "clock_drift_calibration",
                          # "temperature_calibration",
                          # "humidity_calibration",
                          # "pressure_calibration",
                          # "battery_calibration",
                          # "sleep_time_ms",
                          # "high_water_slot"
}
```

If the server cannot find the relevant config file, it will respond with a
single newline character `\n`.

If the server is able to find the relevant config file, it will respond with 3
concatenated parameters:
1. The size of the file data (formatted as an ASCII string) followed by a
   newline character.
2. The md5sum of the file data followed by a newline character.
3. The byte data contents of the file.

Note that the final parameter is not a string and not terminated with a newline
character. In practice, the content of the config files will be ASCII strings,
but this response format is more general and could support binary data if
needed.

**delete_config**  
The delete_config command requests the server to delete a configuration update file and no longer inform the sensor node about it. This is used after the
sensor node has applied the configuration update.

```json
{
  "version":2,
  "node":String,             #name of the sensor node
  "firmware":String,         #firmware name/identifier (preinit_magic)
  "command":"delete_config",
  "arg":String               #the filename requested
                             #possible strings for the filename arg are:
                             # "node_name",
                             # "report_host_name",
                             # "report_host_port",
                             # "clock_drift_calibration",
                             # "temperature_calibration",
                             # "humidity_calibration",
                             # "pressure_calibration",
                             # "battery_calibration",
                             # "sleep_time_ms",
                             # "high_water_slot"
}
```

The server will respond with a single newline character `\n`.

**update**  
The update command requests the server to send the waiting firmware update.

```json
{
  "version":2,
  "node":String,      #name of the sensor node
  "firmware":String,  #firmware name/identifier (preinit_magic)
  "command":"update",
  "arg":String        #the firmware name for the sensor node
                      #typical strings for the firmware name arg are:
                      # "iotsp-battery",
                      # "iotsp-tethered"
}
```

If the server cannot find the relevant firmware update file, it will respond
with the string, `0\n`.

If the server is able to find the relevant firmware update file, it will respond
with 3 concatenated parameters:
1. The size of the update file data (formatted as an ASCII string) followed by a
   newline character.
2. The md5sum of the update file data followed by a newline character.
3. The byte data contents of the firmware update file.

Note that the final parameter is not a string and not terminated with a newline
character. This will be binary file data directly transmitted.

#### Node-RED SOH Monitor

##### Description

Node-RED Flows Overview  
The [Node-RED SOH Monitor](../node-red/soh-monitor.sh) is a helper utility that
can monitor the Systemd Journal for regular heartbeat messages coming from the
[Node-RED Flows](#node-red-flows).  
It is an entirely optional part of the system but can improve reliability. It is
probably less necessary with newer versions of Node-RED.

##### Dependencies

The SOH monitor depends on [systemd](https://systemd.io/) for `systemctl` and
`journalctl`.  
It also uses relies on bash rather than a basic bourne shell for some scripting
extensions.

##### Configuration

The main configuration interface is via command line parameters.
These are optional:
* If 1 parameter is supplied, it is: timeout
* If 2 parameters are supplied: timeout, action count
* If 3 parameters are supplied: timeout, action count, max errors

The timeout parameter represents the time (in seconds) to wait before noticing a
SOH failure. The script expects to see "SOH report" in the journald log for
Node-RED within this time period.  
Default value is 45 seconds.

The action count parameter indicates how many SOH failures to wait for before
taking action to restart the Node-RED server.  
Default value is 3.

The max errors parameter indicates when to give up and stop monitoring. If this
many errors are accumulated in the lifetime of the process, it will exit and
monitoring will stop.  
Default value is 10000.

The default values for these parameters can also be modified at the top of
[the script](../node-red/soh-monitor.sh).  
There is an additional parameter there, `RELOAD_TIME` which represents the
amount of time to wait after restarting Node-RED before monitoring will resume.  
It defaults to 10 seconds, which is adequate for a Raspberry PI 3 to restart the Node-RED server and flows.

> 🪧 Note: The script expects Node-RED to be running under the "user" service
> manager rather than the "system" service manager. This should probably be
> made more configurable or allow some level of auto-detection.

##### Public API

Sending SIGINT to the monitor subprocess will cause it to print out the number
of SOH failures seen so far.

If you are running the script from an interactive shell, pressing CTRL-C will
cause this SIGINT behavior. Pressing CTRL-C again within the timeout period will
terminate the script.

The script is normally expected to be invoked by systemd from the
[unit file provided](../node-red/node-red-soh.service).

--------------------------------------------------------------------------------

## Dynamic Behavior

### Modes of Operation

Server State Diagram

* At startup, systemd initializes the Node-RED Server, SOH Monitor, Grafana, and
  InfluxDB.
* While idle:
  - The Node-RED flows will emit an SOH heartbeat every 30 seconds.
  - The Node-RED flows wait for an incoming connection on port 2880.
* If a connection is initiated, the request will be processed and a response
  sent back.
* If the SOH Monitor fails to see the heartbeat message after 135 seconds, it
  will request systemd to restart the Node-RED server.
* At shutdown, systemd will terminate the servers and SOH monitor in an orderly
  fashion.

### Process Request

#### Measurement

Measurement Processing Sequence Diagram  
Measurements are batched together until the uptime measurement is received. Then
the [Node-RED Flows](#node-red-flows) provide a bulk update to
[InfluxDB](#influxdb).  
The response to the sensor node can be "error" if some problem occurs with
parsing or writing to InfluxDB (not shown). Additionally, the response can
include flags indicating the presence of a waiting firmware or configuration
update (see next section).

#### Firmware Update

Firmware Update Processing Sequence Diagram  
Firmware updates files are looked up in the "firmware" dir by searching for a
base filename provided by the sensor node. If found, the response will include
the file length, md5sum, and data.

#### Configuration Update

Configuration Update Processing Sequence Diagram  
Configuration files are looked up in the "sensor-cfg" dir by searching for the
sensor node name and the filename requested by the sensor node. If found, the
response will include the file length, md5sum, and data.

After retrieving each configuration file and applying the update to its file
system, the sensor node will request the server to delete the configuration
file.  
Configuration Update Processing Sequence Diagram

### Node-RED SOH Behavior

Node-RED SOH Monitoring Sequence Diagram  
The [Node-RED Flows](#node-red-flows) periodically log a message to the console
every 30 seconds.  
Independently, the [Node-RED SOH Monitor](#node-red-soh-monitor) monitors the
systemd journal for the SOH messages with a timeout of 45 seconds.  If the
timeout occurs 3 times, it will invoke systemctl to restart the
[Node-RED](#node-red) server.

### Visualization

Grafana Visualization Sequence Diagram  
A user can connect to the [Grafana](#grafana) web server with a standard web
browser to monitor and visualize the sensor data stored in
[InfluxDB](#influxdb).

--------------------------------------------------------------------------------

## Cybersecurity

> ⚠️ Caution: Cybersecurity was not a primary design consideration for the
> system.  
> Using this system outside of a "hobbyist" environment is not recommended and
> any serious use would require a thorough threat analysis and risk assessment
> (TARA).  
> It is worth reviewing the
> [Cybersecurity](system_architecture.md#cybersecurity) section of the system
> architecture as a starting point.

### Node-RED Security

By default, the Node-RED flow editor is unsecured. Anyone with access to the network can modify its behavior and responses to the sensor nodes. Likewise, the
debug console can be used to monitor the incoming sensor readings.

> ⚠️ Caution: Only run Node-RED in a trusted local network environment.

This page, [Securing Node-RED](https://nodered.org/docs/user-guide/runtime/securing-node-red), provides some information on how to improve the security of Node-RED and add user-authentication. However, it is still probably unwise to expose Node-RED to the public internet.

The TCP connection on port 2880 between the sensor nodes and Node-RED is
unauthenticated. The sensor nodes will connect to any server and believe that it
is the correct destination.  
Further, the sensor nodes will obey any response received from the Node-RED
server -- including [firmware updates](#ota-update). This makes it relatively
trivial for an attacker with access to the WiFi network (or who can spoof the
network) to upload arbitrary firmware to the sensor nodes.

It may be possible to set up SSL certificates for the Node-RED server.  
The ESP8266 can make SSL connections and might even have some basic ability
for certificate pinning. The latter would probably be necessary to be able to
have any significant trust in the authentication of the server; unfortunately,
it would also require some code modifications to add support.

### InfluxDB Security

By default, the InfluxDB database is unsecured. Anyone with access to the
network can perform queries that inject or modify stored data. Likewise, users
with shell access to the host where the server is running can probably access
the InfluxDB console and perform arbitrary administrative operations.

> ⚠️ Caution: Only run InfluxDB in a trusted environment with appropriate
> firewall configuration.

The InfluxDB documentation provides some guidance for
[managing security and authorization](https://docs.influxdata.com/influxdb/v2/admin/security/).

### Grafana Security

By default, the Grafana server does not require user authentication. Anyone with
access to the local network can view the sensor readings.  
Typically, users can also create their own dashboards to execute arbitrary
queries to the InfluxDB database. The implications of this threat are unexplored
by the author of this document.

> ⚠️ Caution: Only run Grafana in a trusted local network environment.

This page, [Configure security](https://grafana.com/docs/grafana/latest/setup-grafana/configure-security/), provides some information about securing a Grafana instance. However, it is probably unwise to expose Grafana to the public internet.

### Node-RED Flows Security

The [Node-RED Flows](#node-red-flows) are listening for incoming connections
from the sensor nodes on TCP port 2880. The standard Nodes-RED nodes provide
the listening interface, the joining of fragmented packets, and the parsing of
the received JSON request.

This represents a fair amount of attack surface for buffer overflows, incorrect
parsing, and the like. The software has not been evaluated by any security
assessor or penetration tester.

> ⚠️ Caution: Only run the Node-RED Flows in a trusted local network environment.

It seems likely that an attacker could create a denial-of-service by flooding
the server with connection requests or creating half-open connections.  
This would be unlikely to be mitigated by the
[Node-RED SOH Monitor](#node-red-soh-monitor) since the flows may still output
their heartbeat message as normal.

An appropriate firewall configuration or intrusion detection system may help
mitigate this threat.

--------------------------------------------------------------------------------

## Error Handling

### General Failures

There can be many causes for failure in the system due to the number of
components and unreliable interfaces such as wireless LAN.

The Grafana server can be configured to set health alerts if there are no
sensor updates for some period of time. With this kind of monitoring, there is
broad, end-to-end coverage for almost any type of failure.  
Grafana Alerts  
In this example, an alert is set if the battery voltage on any sensor node drops
below a critical level or if the sensor has not reported in for some amount of time.  
The downside to this type of monitoring is its lack of specificity. If the
sensor fails to report-in, you only know that there is some problem, but not
what the problem is or how to resolve it.

Grafana alerts can trigger an email if a suitable backend is configured.

Another alternative, is to add monitoring in the Node-RED flows. There are many
nodes available for sending data or alerts to different services (for example,
you could send data to an Amazon S3 bucket to be processed or send alerts to
discord or an MQTT broker).

### Node-RED Server Failure

The Node-RED server may freeze, crash, or get stuck in a busy-loop.
This is surely resolved in newer versions, but in older versions[which?] it
occurs about once per week.

Impact:  
The server will not be able to accept incoming connections.

Mitigation:  
The [Node-RED Flows](#node-red-flows) include a periodic state-of-health message
that is printed to the console. The provided
[soh-monitor.sh](../node-red/soh-monitor.sh) script can monitor the systemd
journal for these state-of-health messages and restart the Node-RED server if a
timeout is exceeded.

More details are provided above:
* [Node-RED SOH Monitor](#node-red-soh-monitor)
* [Node-RED SOH Behavior](#node-red-soh-behavior)

### Node-RED Packet Handling

A lot of effort in the Node-RED flows is spent handling edge-cases with dropped
or partially received packets. While the setup is fairly stable at this point,
it is conceivable that changes may be needed in other environments or if
Node-RED is updated to a new version.

If this happens, the Node-RED flows can be debugged via the web interface on
port 1880.  
To enable additional debug logging, simply click the green button next to one of
the debug nodes. There is no need to "deploy" the flows unless you want the
change to the setting to be remembered permanently.  
Debug Level Modification Screenshot

More detail about the expected output from these debug nodes will be documented
in the [Server Software Design Document](server_design_detail.md).

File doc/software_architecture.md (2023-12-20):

# Sensor Software Architecture

## Table of Contents
* [Block Diagram](#block-diagram)
* [External Dependencies](#external-dependencies)
* [Component Description](#component-description)
  - [Main](#main)
  - [Project Configuration](#project-configuration)
  - [Connectivity](#connectivity)
    + [Connection Manager](#connection-manager)
    + [Update Parser](#update-parser)
    + [WiFi Manager](#wifi-manager)
  - [Sensors](#sensors)
    + [SHT30](#sht30)
    + [HP303B](#hp303b)
    + [Pulse2](#pulse2)
  - [RTC Mem](#rtc-mem)
  - [Persistent Storage](#persistent-storage)
  - [E-Paper Display](#e-paper-display)
* [Dynamic Behavior](#dynamic-behavior)
  - [Interrupts](#interrupts)
  - [Modes of Operation](#modes-of-operation)
    + [Static Modes](#static-modes)
      * [Development Mode](#development-mode)
      * [Battery Mode](#battery-mode)
      * [Tethered Mode](#tethered-mode)
      * [VCC Cal Mode](#vcc-cal-mode)
    + [Dynamic Modes](#dynamic-modes)
      * [Configuration Mode](#configuration-mode)
      * [Initialization](#initialization)
      * [Normal Mode](#normal-mode)
      * [Deep Sleep](#deep-sleep)
      * [Connectivity Mode](#connectivity-mode)
* [Cybersecurity](#cybersecurity)
* [Error Handling](#error-handling)

---

## Block Diagram

Software Stack  
The sensor node software can be roughly decomposed into a software stack
including applications, middleware, drivers, and SDK (which includes low-level
drivers).  
There are 2 main applications: Main, which handles normal business logic of the
sensor; and the Connection Manager, which handles connection to the WiFi network
and interaction with the Node-RED server.  
A third application is the WiFi Manager, which is more properly located in the
middleware layer since its behavior and configuration are managed by the
Connection Manager.  
The driver layer is composed of high-level drivers that are implemented using
the Arduino and ESP SDK functionalities.  
The SDK layer provides Arduino HAL functionalities as well as ESP8266-specific
low-level drivers.

---

## External Dependencies

| External Dependency | Tested Version | Link
|---|---|---
| Arduino IDE | 2.0.3 | https://www.arduino.cc/
| ESP SDK | 3.0.2 | https://github.com/esp8266/Arduino
| * lwIP | 2.1.2 | Part of ESP SDK - website: https://www.nongnu.org/lwip
| WiFi Manager | 0.16.0 | https://github.com/tzapu/WiFiManager
| Lolin HP303B | commit 4deb5f  | https://github.com/wemos/LOLIN_HP303B_Library

---

## Component Description

### Main

##### Description

Main Component Overview  
The Main component provides the familiar entry point functions for the Arduino
framework (e.g. `setup` and `loop`).  
It orchestrates the collection and display of sensor readings as well as
changes between modes of operation for the sensor node.

##### Dependencies

| Component | Interface Type | Description
|---|---|---
| Connection Manager | function | Connectivity API
| Sensors | function | Sensor readings API
| RTC Mem | function, global | Sleep API, RTC Memory API
| EPD_1in9 | function | E-Paper Display API
| ResetInfo | function | Reset reason detects double-press of reset button
| Waveform | function | Blink LED at constant rate
| Wiring | function | GPIO API, delay API
| Project Configuration | preprocessor macro | Configuration settings
| Serial | class | Logging printf

##### Configuration

Configuration of this component is done through preprocessor defines set in
[project_config.h](../project_config.h).

| Configuration | Type | Description
|---|---|---
| EXTRA_DEBUG | bool | Enables additional debug logging
| TETHERED_MODE | bool | Enables PPD42 sensor
| VCC_CAL_MODE | bool | Builds for VCC Calibration mode (allows quick reading of VCC ADC to assist with calibration)
| SERIAL_SPEED | unsigned long | Baud rate for the logging serial port
| LOW_BATTERY_VOLTAGE | float | Voltage level at which the low battery icon will be set on the display
| CRIT_BATTERY_VOLTAGE | float | Voltage level at which the critically low battery message will be displayed
| DISP_CONNECT_FAIL_COUNT  | unsigned int  | Number of failed connections that will trigger the connection error message to be displayed
| MAX_ESP_SLEEP_TIME_MS | uint64_t | Value that represents an "infinite" sleep time
| PPD42_PIN_DET | uint8_t | Pin # used to detect presence of PPD42 sensor
| EPD_FULL_REFRESH_TIME_MS | uint64_t | Period between full display refreshes in milliseconds
| EPD_RST_PIN | uint8_t | Pin number for the EPD reset pin
| EPD_RST_POLARITY | bool | Indicates whether reset pin is active high or low
| EPD_FAHRENHEIT | bool | Indicates whether display temp is in °F rather than °C
| SIMULATE_GOOD_CONNECTION | bool | Enables debug mode where upload is not actually performed

##### Public API

###### Types and Enums
None

###### Functions

preinit
> Called before global class instances are initialized.  
> Calls `connectivity_preinit` to disable the modem before it gets initialized.
>
> 🪧 Note: This function is only used in non-tethered mode.
> In tethered mode, the WiFi radio is left active permanently.
>
> | Parameter     | Direction | Type          | Description
> |---------------|-----------|---------------|-------------
> |               | return    | void          |

setup
> Called before the main processing loop starts.  
> Initializes the Serial port and RTC Memory.  
> Checks the reset reason and decides whether to start WiFi Manager or
> run the normal sensor processing.
>
> | Parameter     | Direction | Type          | Description
> |---------------|-----------|---------------|-------------
> |               | return    | void          |

loop
> Executes the normal sensor processing.  
> Despite the name, this function normally does not loop.
> In battery mode, it always ends in a deep sleep.
> In tethered mode, it may or may not enter deep sleep depending on how long
> the sensor processing and upload process took.
>
> | Parameter     | Direction | Type          | Description
> |---------------|-----------|---------------|-------------
> |               | return    | void          |

##### Critical Sections

None

### Project Configuration

Project Confguration Overview  
The Project Configuration header, [project_config.h](../project_config.h),
provides a central location for configuring the behavior of the sensor node.

##### Dependencies

None

##### Configuration

There are 4 main configurations that can be set in this file to control high-
level behavior of the sensor node:

| Configuration | Type | Description
|---|---|---
| EXTRA_DEBUG | bool | Enables additional debug logging
| TETHERED_MODE | bool | Configures the Sensor to run from an unlimited power supply -- enables PPD42 sensor and uploads sensor readings to the server every cycle
| DEVELOPMENT_BUILD | bool | Enables settings helpful for the developer or for debugging -- enables EXTRA_DEBUG, reduces sleep time and number of storage slots, and disables remote firmware updates
| VCC_CAL_MODE | bool | Enables a mode for calibrating the VCC ADC -- this combines `DEVELOPMENT_BUILD` with `TETHERED_MODE` to provide rapid feedback about the battery voltage

There are additional configurations that may be changed based on user
preferrence:

| Configuration | Type | Description
|---|---|---
| SERIAL_SPEED | unsigned long | Baud rate for the logging serial port
| REPORT_RESPONSE_TIMEOUT | unsigned long | Timeout period (in milliseconds) to wait for a response from the Node-RED server
| LOW_BATTERY_VOLTAGE | float | Voltage level at which the low battery icon will be set on the display
| DISP_CONNECT_FAIL_COUNT | unsigned int  | Number of failed connections that will trigger the connection error message to be displayed
| FIRMWARE_NAME | const char* | Prefix for the firmware file name that will be communicated to the Node-RED server (must match the filename of the firmware files stored on the server)
| EPD_FAHRENHEIT | bool | Indicates whether display temp is in °F rather than °C
| SLEEP_TIME_MS | int | Default time to sleep between sensor readings in milliseconds (note: configurable through WiFi Manager)

**The remaining configurations in this file are mostly things that you would not
have a need to change.**

There are several hardware-specific configurations that would need to be changed
if different or modified hardware was used:

| Configuration | Type | Description
|---|---|---
| SHT30_ADDR | uint8_t | I2C Address for the SHT30 sensor
| PPD42_PIN_DET | uint8_t | Pin # used to detect presence of PPD42 sensor
| PPD42_PIN_1_0 | uint8_t | Pin # used as LPO output of PPD42 sensor for PM1.0 detections
| PPD42_PIN_2_5 | uint8_t | Pin # used as LPO output of PPD42 sensor for PM2.5 detections
| EPD_BUSY_PIN | uint8_t | Pin number for the EPD busy pin
| EPD_RST_PIN | uint8_t | Pin number for the EPD reset pin
| EPD_RST_POLARITY | bool | Indicates whether reset pin is active high or low

The file names and default values used in persistent storage are configurable,
but you would mostly not want to change these as the values are intended to be
updated through WiFi Manager as an end-user setup step:

| Configuration | Type | Description
|---|---|---
| PERSISTENT_NODE_NAME | const char* | Filename where the node name is stored in SPIFFS
| PERSISTENT_REPORT_HOST_NAME | const char* | Filename where the Node-RED server hostname is stored in SPIFFS
| PERSISTENT_REPORT_HOST_PORT | const char* | Filename where the Node-RED server port number is stored in SPIFFS
| PERSISTENT_CLOCK_CALIB | const char* | Filename where the clock calibration (bootup time and sleep drift correction) is stored in SPIFFS
| PERSISTENT_TEMP_CALIB | const char* | Filename where the temperature calibration is stored in SPIFFS
| PERSISTENT_HUMIDITY_CALIB | const char* | Filename where the humidity calibration is stored in SPIFFS
| PERSISTENT_PRESSURE_CALIB | const char* | Filename where the pressure calibration is stored in SPIFFS
| PERSISTENT_BATTERY_CALIB | const char* | Filename where the battery (VCC ADC) calibration is stored in SPIFFS
| PERSISTENT_SLEEP_TIME_MS | const char* | Filename where the sleep time configuration is stored in SPIFFS
| PERSISTENT_HIGH_WATER_SLOT  | const char* | Filename where the high water slot (upload trigger) configuration is stored in SPIFFS
| DEFAULT_NODE_BASE_NAME | const char* | Prefix string for default node name (ESP serial number is appended) if no value stored in SPIFFS
| DEFAULT_REPORT_HOST_NAME | const char* | Default hostname for the Node-RED server if no value stored in SPIFFS
| DEFAULT_REPORT_HOST_PORT | int | Default port number for the Node-RED server if no value stored in SPIFFS
| DEFAULT_SLEEP_CLOCK_ADJ | int | Default clock calibration if no value stored in SPIFFS
| DEFAULT_TEMP_CALIB | float | Default temperature calibration if no value stored in SPIFFS
| DEFAULT_HUMIDITY_CALIB | float | Default humidity calibration if no value stored in SPIFFS
| DEFAULT_PRESSURE_CALIB | float | Default pressure calibration if no value stored in SPIFFS
| DEFAULT_BATTERY_CALIB | float | Default battery calibration (VCC ADC) if no value stored in SPIFFS
| DEFAULT_SLEEP_TIME_MS | int | Default sleep time if no value stored in SPIFFS
| DEFAULT_HIGH_WATER_SLOT | size_t | Default high water slot (upload trigger) if no value stored in SPIFFS

The remaining configurations do impact the behavior of the software but the need
to change them is dubious (and in some cases would require changes in the
software modules that use them):

| Configuration | Type | Description
|---|---|---
| CONFIG_SERVER_MAX_TIME | unsigned long | Timeout period (in seconds) for the WiFi Manager configuration portal
| WIFI_CONNECT_TIMEOUT | unsigned long | Timeout period (in milliseconds) for connecting to the WiFi
| CRIT_BATTERY_VOLTAGE | float | Voltage level at which the critically low battery message will be displayed
| DISP_CONNECT_FAIL_COUNT  | unsigned int | Number of failed connections that will trigger the connection error message to be displayed
| MAX_ESP_SLEEP_TIME_MS | unsigned long long | Clamps requested sleep time since there is a bug if the value is too large; represents an "infinite" sleep time
| DISABLE_FW_UPDATE | bool | Ignores firmware update notices from the Node-RED server -- useful for development since you will always have an "unknown" software version (unless debugging the firmware update process is your goal)
| SIMULATE_GOOD_CONNECTION | bool | Enables debug mode where upload is not actually performed -- may need to be disabled when debugging connection and upload issues during development
| NUM_STORAGE_SLOTS | size_t | Maximum number of sensor readings that can be stored in RTC Memory
| HIGH_WATER_SLOT | size_t | Determines the threshold for collected sensor readings that triggers an upload process

##### Public API

###### Types and Enums

PREINIT_MAGIC
> This preprocessor definition is not really configurable, but serves as a
> "fingerprint" for the software. It is created by hashing the build timestamp
> with a magic number.  
> The goal is to be able to provide a software "version" without any semantics
> behind it. The git commit hash would probably be better
> for this purpose, but the build system in Arduino is not particularly
> accessible for injecting this kind of information into the preprocessor.
>
> This fingerprint is used to detect when the existing RTC Mem contents are
> out-of-date (for example after a firmware update or on a cold boot).
>
> The Node-RED server will use this fingerprint to determine if an update needs
> to be sent to the sensor node and will also store it with the sensor readings
> in the database in case it would be useful for filtering later.

###### Functions

None

##### Critical Sections

None

### Connectivity

Connectivity Subsystem Overview

Connection Manager and WiFi Manager are the main components that make up the
Connectivity Subsystem. These rely on Arduino WiFi APIs and ESP8266
implementations of WiFiStation and WiFiSoftAP, respectively, to handle WiFi
connectivity aspects.

Connection Manager is the main entry point to the Connectivity Subsystem
regardless of the type of activity to be performed. Typically, it is triggered
to upload sensor readings to the Node-RED server periodically. When starting the
configuration mode, the Connection Manager configures WiFi Manager and
establishes various callback functions before handing off control to it to
create the captive configuration portal. These callback functions will handle
updates to the configuration by storing the new values in persistent storage.

Update Parser handles interactions with the Node-RED server to update the
firmware or configurations.

#### Connection Manager

##### Description

Sensors Component Overview  
The Connection Manager component handles the upload of sensor readings to the
Node-RED server. If there are firmware or configuration updates, it hands the
connection off to the Update Parser to handle these.  
When the user requests to enter configuration mode via a double press of the
reset button, Main informs the Connection Manager and it configures WiFi Manager
to create a captive configuration portal. WiFi Manager provides results in the
form of a callback function and Connection Manager implements this callback by
updating the values in persistent storage.

> ☝‍🎗 Note: this component exhibits high coupling and should be refactored by
> splitting-out config-mode handling and update parser functionality.

##### Dependencies

| Component | Interface Type | Description
|---|---|---
| libstdc++ | class | `String` class
| ChipId | function | API for getting the Chip ID (serial number)
| UpdateParser | function | Handle firmware and configuration updates from the Node-RED server
| WiFiManager | class | WiFi Manager configuration
| Persistent Storage | function | Read and Write configuration parameters to SPIFFS
| RTC Mem | global, function | Sensor readings management, uptime calculation
| WiFi | class | High-level WiFi configuration API
| WiFiClient | class | High-level Socket connection API
| WiFiGenericClass | class | `preinitWiFiOff` API
| WiFiStation | function | `station_config` APIs
| Wiring | function | `delay`, `millis` API
| Project Configuration | preprocessor macro | Configuration settings
| Serial | class | Logging printf

##### Configuration

Configuration of this component is done through preprocessor defines set in
[project_config.h](../project_config.h).

| Configuration | Type | Description
|---|---|---
| EXTRA_DEBUG | bool | Enables additional debug logging
| TETHERED_MODE | bool | Determines whether to auto-enable WiFi at startup
| REPORT_RESPONSE_TIMEOUT | unsigned long | Timeout period (in milliseconds) to wait for a response from the Node-RED server after uploading readings
| WIFI_CONNECT_TIMEOUT | unsigned long | Timeout period (in milliseconds) for connecting to the WiFi
| NUM_STORAGE_SLOTS | size_t | Maximum number of sensor readings that can be stored in RTC Memory
| PERSISTENT_NODE_NAME | const char* | Used to retreive the sensor node hostname from SPIFFS
| PERSISTENT_REPORT_HOST_NAME | const char* | Used to retreive the hostname of the Node-RED server from SPIFFS
| PERSISTENT_REPORT_HOST_PORT | const char* | Used to retrieve the port number of the Node-RED server from SPIFFS
| PERSISTENT_TEMP_CALIB | const char* | Used to retrieve the temperature calibration from SPIFFS
| PERSISTENT_HUMIDITY_CALIB | const char* | Used to retrieve the humidity calibration from SPIFFS
| PERSISTENT_PRESSURE_CALIB | const char* | Used to retrieve the pressure calibration from SPIFFS
| PERSISTENT_BATTERY_CALIB | const char* | Used to retrieve the battery calibration from SPIFFS
| DEFAULT_NODE_BASE_NAME | const char* | Prefix string for default node hostname (ESP serial number is appended) if no value stored in SPIFFS
| DEFAULT_REPORT_HOST_NAME | const char* | Default hostname for the Node-RED server if no value stored in SPIFFS
| DEFAULT_REPORT_HOST_PORT | int | Default port number for the Node-RED server if no value stored in SPIFFS
| DEFAULT_TEMP_CALIB | float | Default temperature calibration if no value stored in SPIFFS
| DEFAULT_HUMIDITY_CALIB | float | Default humidity calibration if no value stored in SPIFFS
| DEFAULT_PRESSURE_CALIB | float | Default pressure calibration if no value stored in SPIFFS
| DEFAULT_BATTERY_CALIB | float | Default battery calibration if no value stored in SPIFFS

Additionally, the following preprocessor defines are used to modify the configuration of WiFi Manager:

| Configuration | Type | Description
|---|---|---
| CONFIG_SERVER_MAX_TIME | unsigned long | Timeout period (in seconds) for the WiFi Manager configuration portal
| MAX_ESP_SLEEP_TIME_MS | unsigned long long | Clamps requested sleep time configuration

Also, each of the PERSISTENT_* and DEFAULT_* persistent storage preprocessor
defines are used to initialize the current value shown by the WiFi Manager
configuration page and used by the callback implementation to write the updated
values back to SPIFFS.

##### Public API

###### Types and Enums
None

###### Functions

connectivity_preinit
> Calls `ESP8266WiFiClass::preinitWiFiOff` to disable the modem before it gets
> initialized.  
> Expected to be called from the pre-init function before global class instances
> are initialized.
>
> 🪧 Note: This function is only used in non-tethered mode.
> In tethered mode, the WiFi radio is left active permanently.
>
> | Parameter     | Direction | Type          | Description
> |---------------|-----------|---------------|-------------
> |               | return    | void          |

connectivity_init
> Initializes the Connection Manager
>
> | Parameter     | Direction | Type          | Description
> |---------------|-----------|---------------|-------------
> |               | return    | void          |

connectivity_disable
> Shuts down WiFi
>
> | Parameter     | Direction | Type          | Description
> |---------------|-----------|---------------|-------------
> |               | return    | void          |

connect_wifi
> Connects to the stored WiFi Access Point
>
> | Parameter     | Direction | Type          | Description
> |---------------|-----------|---------------|-------------
> |               | return    | bool          | Returns false if there was a connection error or timeout

enter_config_mode
> Start the WiFi Manager configuration mode
>
> | Parameter     | Direction | Type          | Description
> |---------------|-----------|---------------|-------------
> |               | return    | void          |

upload_readings
> Collates and uploads readings to the report server.
>
> ☝‍🎗 Note: this function exhibits high coupling with the RTC Memory and should
> be refactored.
>
> | Parameter     | Direction | Type          | Description
> |---------------|-----------|---------------|-------------
> |               | return    | void          |

##### Critical Sections

None

> ⚠️ Caution: This component is not threadsafe.  
> The functions of this component are not reentrant.  
> Calling `upload_readings` from a context that might be preempted by callers
> of the RTC Mem component could result in corruption of the sensor reading
> circular buffer.

#### Update Parser

##### Description

Update Parser Component Overview  
The Update Parser component retrieves firmware or configuration updates from the
Node-RED server and applies them to the program flash or persistent storage
filesystem, respectively.

> ☝‍🎗 Note: this component exhibits high coupling and should be refactored as a
> separate module.

##### Dependencies

| Component | Interface Type | Description
|---|---|---
| libstdc++ | class | `String` class
| Persistent Storage | function | Write configuration parameter updates to SPIFFS
| RTC Mem | global, function | Update configuration parameters in RTC memory, invalidate RTC memory on firmware update
| MD5Builder | class | Calculate md5sum
| Updater | class, function | Performs firmware update
| WiFiClient | class | High-level Socket connection API
| Wiring | function | `delay` API
| Project Configuration | preprocessor macro | Configuration settings
| Serial | class | Logging printf

##### Configuration

Configuration of this component is done through preprocessor defines set in
[project_config.h](../project_config.h).

| Configuration | Type | Description
|---|---|---
| EXTRA_DEBUG | bool | Enables additional debug logging
| DISABLE_FW_UPDATE | bool | Disables firmware update functionality
| FIRMWARE_NAME | const char* | Prefix for the firmware file name that will be requested from the Node-RED server
| MAX_ESP_SLEEP_TIME_MS | unsigned long long | Clamps requested sleep time configuration
| NUM_STORAGE_SLOTS | size_t | Maximum number of sensor readings that can be stored in RTC Memory
| PERSISTENT_NODE_NAME | const char* | Filename where the node name is stored in SPIFFS
| PERSISTENT_REPORT_HOST_NAME | const char* | Filename where the Node-RED server hostname is stored in SPIFFS
| PERSISTENT_REPORT_HOST_PORT | const char* | Filename where the Node-RED server port number is stored in SPIFFS
| PERSISTENT_CLOCK_CALIB | const char* | Filename where the clock calibration (bootup time and sleep drift correction) is stored in SPIFFS
| PERSISTENT_TEMP_CALIB | const char* | Filename where the temperature calibration is stored in SPIFFS
| PERSISTENT_HUMIDITY_CALIB | const char* | Filename where the humidity calibration is stored in SPIFFS
| PERSISTENT_PRESSURE_CALIB | const char* | Filename where the pressure calibration is stored in SPIFFS
| PERSISTENT_BATTERY_CALIB | const char* | Filename where the battery (VCC ADC) calibration is stored in SPIFFS
| PERSISTENT_SLEEP_TIME_MS | const char* | Filename where the sleep time configuration is stored in SPIFFS
| PERSISTENT_HIGH_WATER_SLOT  | const char* | Filename where the high water slot (upload trigger) configuration is stored in SPIFFS
| DEFAULT_TEMP_CALIB | float | Default temperature calibration if no value stored in SPIFFS
| DEFAULT_HUMIDITY_CALIB | float | Default humidity calibration if no value stored in SPIFFS
| DEFAULT_BATTERY_CALIB | float | Default battery calibration (VCC ADC) if no value stored in SPIFFS
| DEFAULT_SLEEP_TIME_MS | int | Default sleep time if no value stored in SPIFFS
| DEFAULT_HIGH_WATER_SLOT | size_t | Default high water slot (upload trigger) if no value stored in SPIFFS

##### Public API

###### Types and Enums

None

###### Functions

update_config
> Performs the configuration update procedure by requesting the configuration
> files from the Node-RED server along with their size and MD5 checksum.
> Updates the files in SPIFFS if the MD5 checksum passes.
>
> | Parameter | Direction | Type        | Description
> |-----------|-----------|-------------|-------------
> |           | return    | bool        | Returns false if there was an error during the update process.
> | client    | in        | WiFiClient& | Client connection to the Node-RED server. Used to send and receive communication with the server.

update_firmware
> Performs the firmware update procedure by requesting the firmware file from
> the Node-RED server along with its size and MD5 checksum.
>
> ⚠️ Caution: There is no security check performed on this firmware update. An
> attacker could easily pretend to be the Node-RED server and signal the
> presence of an update and then provide their own firmware binary which will be
> flashed into the sensor node without any verification.
>
> | Parameter | Direction | Type        | Description
> |-----------|-----------|-------------|-------------
> |           | return    | bool        | Returns false if the update failed. Does not return if the update succeeded.
> | client    | in        | WiFiClient& | Client connection to the Node-RED server. Used to send and receive communication with the server.

##### Critical Sections

None

> 🪧 Note: One assumes that the underlying ESP.updateSketch SDK is written in a
> thread-safe way, but I have not investigated this detail myself.

#### WiFi Manager

##### Description

WiFi Manager Component Overview  
The WiFi Manager component implements a configuration interface for the user by
acting as a WiFi access point with a captive portal.  
This component is provided as an external dependency developed by
[@tzapu](https://github.com/tzapu).
See https://github.com/tzapu/WiFiManager for more details.

##### Dependencies

| Component | Interface Type | Description
|---|---|---
| libstdc++ | class | `String`, `<memory>`
| ChipId | function | API for getting the Chip ID (serial number)
| DNSServer | class | DNS Server used to implement captive portal
| WebServer | class | Web Server used to provide configuration page via the captive portal
| WiFi | class | High-level WiFi configuration API
| WiFiSoftAP | class | WiFi Software Access Point implementation
| Wiring | function | `delay`, `millis` API

##### Configuration

WIFI_MANAGER_MAX_PARAMS
> This parameter defines the initial memory allocated for parameters.
> If memory is tight it may be useful to configure this before including the
> `WiFiManager.h` header.

##### Public API

###### Types and Enums

WiFiManagerParameter
> Class to create custom parameters that can be added to the WiFiManager setup
> web page.

WiFiManager
> Class to configure and interact with the WiFiManager.

###### Functions

> 🪧 Note: For brevity only used interfaces are shown here. For the complete API
> see https://github.com/tzapu/WiFiManager/blob/master/README.md.

WiFiManagerParameter::WiFiManagerParameter
> Constructor for a custom parameter
>
> | Parameter    | Direction | Type        | Description
> |--------------|-----------|-------------|-------------
> | id           | in        | const char* | Unique ID used for HTTP queries and must not contain spaces nor other special characters
> | placeholder  | in        | const char* | "hint" text that will be shown in the input form
> | defaultValue | in        | const char* | Initial value to be placed in the input form
> | length       | in        | int         | Maximum length for the form input
> | custom       | in        | const char* | Custom HTML to be added into the input form

WiFiManagerParameter::getValue
> Function to return the value stored in the custom parameter.
>
> | Parameter | Direction | Type        | Description
> |-----------|-----------|-------------|-------------
> |           | return    | const char* | The value stored in the custom parameter (either the defaultValue or NULL, or the value entered by the user in the input form)

WiFiManager::WiFiManager
> Void constructor

WiFiManager::~WiFiManager
> Destructor

WiFiManager::addParameter
> Adds a custom parameter.
>
> | Parameter | Direction | Type                  | Description
> |-----------|-----------|-----------------------|-------------
> |           | return    | bool                  | Returns false on failure
> | p         | in        | WiFiManagerParameter* | The parameter to add

WiFiManager::setConfigPortalTimeout
> Sets timeout before webserver loop ends and exits even if there has been no
> setup. Useful for devices that failed to connect at some point and got stuck
> in a webserver loop.
>
> | Parameter | Direction | Type          | Description
> |-----------|-----------|---------------|-------------
> |           | return    | void          |
> | seconds   | in        | unsigned long | The timeout after which the webserver will return back to the host software automatically

WiFiManager::setBreakAfterConfig
> Configures WiFiManager to exit after the user submits the updated
> configuration settings, even if connection is unsuccessful.
>
> | Parameter   | Direction | Type    | Description
> |-------------|-----------|---------|-------------
> |             | return    | void    |
> | shouldBreak | in        | boolean | Indicates whether the portal should exit even if the connection to the access point is unsuccessful

WiFiManager::setSaveConfigCallback
> Sets a callback for when settings have been saved by the user.
>
> | Parameter | Direction | Type           | Description
> |-----------|-----------|----------------|-------------
> |           | return    | void           |
> | func      | in        | void (*)(void) | The callback function to register

WiFiManager::startConfigPortal
> Manually starts the config portal without trying to connect first.
>
> | Parameter  | Direction | Type        | Description
> |------------|-----------|-------------|-------------
> |            | return    | boolean     | Indicates whether the connection to the saved access point was successful
> | apName     | in        | char const* | The SSID for the soft AP (defaults to "ESP" + chip ID)
> | apPassword | in        | char const* | Password for the soft AP (defaults to NULL)

### Sensors

##### Description

Sensors Component Overview  
The Sensors component manages the different sensors attached to the sensor node
and stores their readings in RTC memory. It can store the following types of
sensor readings:
* SENSOR_TEMPERATURE
* SENSOR_HUMIDITY
* SENSOR_PRESSURE
* SENSOR_PARTICLE_1_0
* SENSOR_PARTICLE_2_5
* SENSOR_BATTERY_VOLTAGE

Additionally, the pseudo-sensor type SENSOR_TIMESTAMP_OFFS, is used to store a
correlated timestamp with each batch of readings.

##### Dependencies

| Component | Interface Type | Description
|---|---|---
| Pulse2 | class | GPIO pulse duration measurement of LPO from PPD42 particle sensor
| SHT30 | function | I2C driver for SHT30 sensor
| HP303B | class | I2C driver for HP303B sensor
| RTC Mem | global, function | Storage for sensor readings, uptime calculation
| Wiring | function | GPIO HAL
| TwoWire | class | I2C initialization
| ADC_VCC | function | VCC (battery) Voltage sensor HAL
| Project Configuration | preprocessor macro | Configuration settings
| Serial | class | Logging printf

##### Configuration

Configuration of this component is done through preprocessor defines set in
[project_config.h](../project_config.h).

| Configuration | Type | Description
|---|---|---
| EXTRA_DEBUG | bool | Enables additional debug logging
| TETHERED_MODE | bool | Enables PPD42 sensor
| SHT30_ADDR | uint8_t | I2C Address for the SHT30 sensor
| PPD42_PIN_DET | uint8_t | Pin # used to detect presence of PPD42 sensor
| PPD42_PIN_1_0 | uint8_t | Pin # used as LPO output of PPD42 sensor for PM1.0 detections
| PPD42_PIN_2_5 | uint8_t | Pin # used as LPO output of PPD42 sensor for PM2.5 detections

##### Public API

###### Types and Enums

sensor_type_t
> This enum provides labels for the different types of sensor readings.
>
> Enumerations:
> * SENSOR_UNKNOWN
> * SENSOR_TEMPERATURE
> * SENSOR_HUMIDITY
> * SENSOR_PRESSURE
> * SENSOR_PARTICLE_1_0
> * SENSOR_PARTICLE_2_5
> * SENSOR_BATTERY_VOLTAGE
> * SENSOR_TIMESTAMP_OFFS

###### Functions

sensors_init
> Initialize module. 
>
> | Parameter     | Direction | Type          | Description
> |---------------|-----------|---------------|-------------
> |               | return    | void          |

read_ppd42
> Read and store values from the PPD42 particle sensor.
> This measurement is recommended to take 30 seconds.
>
> 🪧 Note: The sensor requires a 3 minute warm-up time so this function is only
> available in tethered mode
> 
> | Parameter     | Direction | Type          | Description
> |---------------|-----------|---------------|-------------
> |               | return    | void          |
> | sampletime_us | in        | unsigned long | measurement time for the sensor in μs

read_sht30
> Read and store values from the SHT30 temperature and humidity sensor.
>
> | Parameter     | Direction | Type          | Description
> |---------------|-----------|---------------|-------------
> |               | return    | void          |
> | perform_store | in        | bool          | If true, the average of the sensor readings collected so far will be stored to RTC memory

read_hp303b
>Read and store values from the HP303B barometric pressure sensor.
>
> | Parameter     | Direction | Type          | Description
> |---------------|-----------|---------------|-------------
> |               | return    | void          |
> | measure_temp  | in        | bool          | If true, the temperature will also be measured using this sensor and stored

read_vcc
> Read and store the ESP VCC voltage level (battery).
>
> | Parameter     | Direction | Type          | Description
> |---------------|-----------|---------------|-------------
> |               | return    | void          |
> | perform_store | in        | bool          | If true, the average of the voltage readings collected so far will be stored to RTC memory

store_uptime
> Store the current uptime as an offset from `RTC_MEM_DATA_TIMEBASE`.
> 
> | Parameter     | Direction | Type          | Description
> |---------------|-----------|---------------|-------------
> |               | return    | void          |

get_temp
> Return the current temperature.
>
> 🪧 Note: The temperature must have already been stored by calling `read_sht30`
> or `read_hp303b`.  
> Otherwise, NAN will be returned.
>
> | Parameter     | Direction | Type          | Description
> |---------------|-----------|---------------|-------------
> |               | return    | float         | The current temperature (°C)

get_humidity
> Return the current relative humidity.
>
> 🪧 Note: The humidity must have already been stored by calling `read_sht30`.  
> Otherwise, NAN will be returned.
>
> | Parameter     | Direction | Type        | Description
> |---------------|-----------|-------------|-------------
> |               | return    | float       | The current relative humidity (%)

get_battery
> Return the current battery voltage.
>
> 🪧 Note: The battery voltage must have already been stored by calling
> `read_vcc`.  
> Otherwise, NAN will be returned.
>
> | Parameter     | Direction | Type          | Description
> |---------------|-----------|---------------|-------------
> |               | return    | float         | The current battery voltage

##### Critical Sections

None

> 🪧 Note: Many of the functions in this component use static data and are not
> reentrant.

#### SHT30

##### Description

SHT30 Component Overview  
The SHT30 driver provides a simple interface to retrieve sensor readings from
one or more SHT30 sensors and helper functions for parsing the data returned.

##### Dependencies

| Component | Interface Type | Description
|---|---|---
| Wiring | function | delay API
| TwoWire | class | I2C API
| lwip | preprocessor macro | ntohs

##### Configuration

There is no static configuration for this component.

##### Public API

###### Types and Enums

sht30_repeatability_t
> This enum provides options for the single-shot capture mode of the sensor.
> Higher repeatability will result in longer duration spent capturing the
> measurement.
>
> Enumerations:
> * SHT30_RPT_LOW
> * SHT30_RPT_MED
> * SHT30_RPT_HIGH

sht30_data_t
> This structure represents the data format returned by the sensor.
>
> Fields:
> * uint16_t temp
> * uint8_t temp_check
> * uint16_t humidity
> * uint8_t humidity_check

###### Functions

sht30_get
> Retrieve a measurement in single-shot mode.
>
> | Parameter | Direction | Type                  | Description
> |-----------|-----------|-----------------------|-------------
> |           | return    | int                   | 0 for success, non-0 for failure
> | addr      | in        | uint8_t               | I2C Address for the sensor
> | type      | in        | sht30_repeatability_t | Measurement type
> | data_out  | out       | sht30_data_t*         | Data structure to return the measurement in - won't be modified on failure

sht30_parse_temp_c
> Convert the data reading into a float temperature value (°C)
> 
> | Parameter | Direction | Type         | Description
> |-----------|-----------|--------------|-------------
> |           | return    | float        | Temperature in °C
> | data      | in        | sht30_data_t | Data structure with the measurement to convert

sht30_parse_temp_f
> Convert the data reading into a float temperature value (°F)
> 
> | Parameter | Direction | Type         | Description
> |-----------|-----------|--------------|-------------
> |           | return    | float        | Temperature in °F
> | data      | in        | sht30_data_t | Data structure with the measurement to convert

sht30_parse_humidity
> Convert the data reading into a float humidity value (RH%)
> 
> | Parameter | Direction | Type         | Description
> |-----------|-----------|--------------|-------------
> |           | return    | float        | Relative humidity
> | data      | in        | sht30_data_t | Data structure with the measurement to convert

sht30_check_temp
> Check the data reading temperature CRC
> 
> | Parameter | Direction | Type         | Description
> |-----------|-----------|--------------|-------------
> |           | return    | bool         | True if CRC OK
> | data      | in        | sht30_data_t | Data structure with the measurement to check

sht30_check_humidity
> Check the data reading humidity CRC
> 
> | Parameter | Direction | Type         | Description
> |-----------|-----------|--------------|-------------
> |           | return    | bool         | True if CRC OK
> | data      | in        | sht30_data_t | Data structure with the measurement to check

##### Critical Sections

None

> 🪧 Note: It isn't recommended to call `sht30_get` from different CPU cores
> simultaneously.
> The behavior of the underlying TwoWire library is likely to be undefined in
> this situation.
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

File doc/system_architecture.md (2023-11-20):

# System Architecture

## Table of Contents
* [Block Diagram](#block-diagram)
* [Features](#features)
  - [Sensor Measurements](#sensor-measurements)
  - [Persistent Storage](#persistent-storage)
  - [Sensor Node Power Management](#sensor-node-power-management)
  - [Connectivity](#connectivity)
  - [Presentation](#presentation)
  - [FW Update](#fw-update)
* [System Modes](#system-modes)
  - [Reprogramming Mode](#reprogramming-mode)
  - [Configuration Mode](#configuration-mode)
  - [Normal Mode](#normal-mode)
  - [Deep Sleep](#deep-sleep)
  - [Upload Mode](#upload-mode)
  - [Download Mode](#download-mode)
* [Failure Modes](#failure-modes)
* [Cybersecurity](#cybersecurity)

---

## Block Diagram
System Architecture Block Diagram

Distributed sensor nodes are powered either by battery or by a USB power supply and communicate with a central server via WiFi.  
Sensor nodes act as WiFi stations and connect to a pre-configured access point. Sensors nodes are pre-configured with a DNS or IP address for the server on the local network.  
The server is running a [Node-RED](https://nodered.org/) instance which is listening for incoming connections. The Node-RED instance will parse out the sensor readings and store them in a time-series database like [InfluxDB](https://www.influxdata.com/).  
[Grafana](https://grafana.com/) can be used to provide a user-friendly interface to view the data. The Grafana instance could run on the same server or on a different server. Grafana provides an HTTP portal to view the data, so users can connect to it from other computers or smartphones that are connected to the network.

---

## Features
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

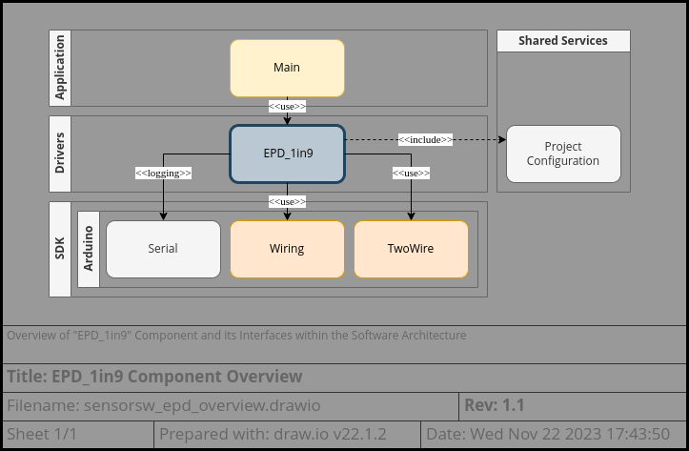
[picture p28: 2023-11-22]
doc/drawio/sensorsw_epd_1in9_overview.png

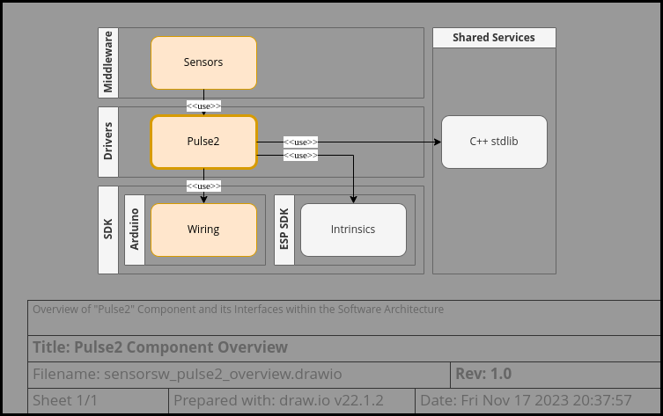
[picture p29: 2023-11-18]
doc/drawio/sensorsw_pulse2_overview.png

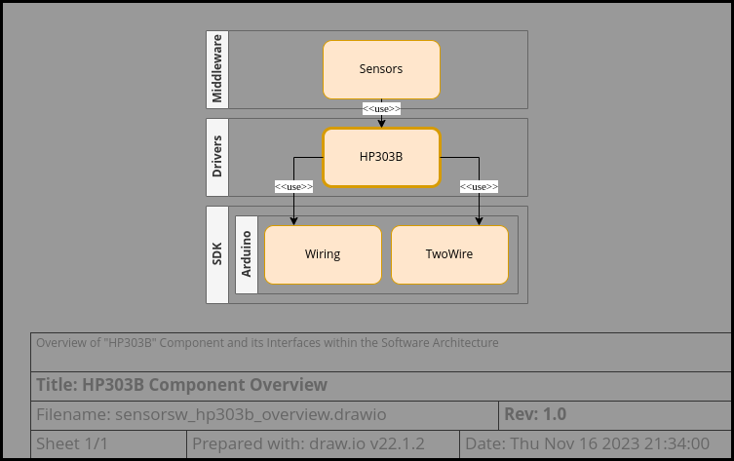
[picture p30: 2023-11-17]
doc/drawio/sensorsw_hp303b_overview.png

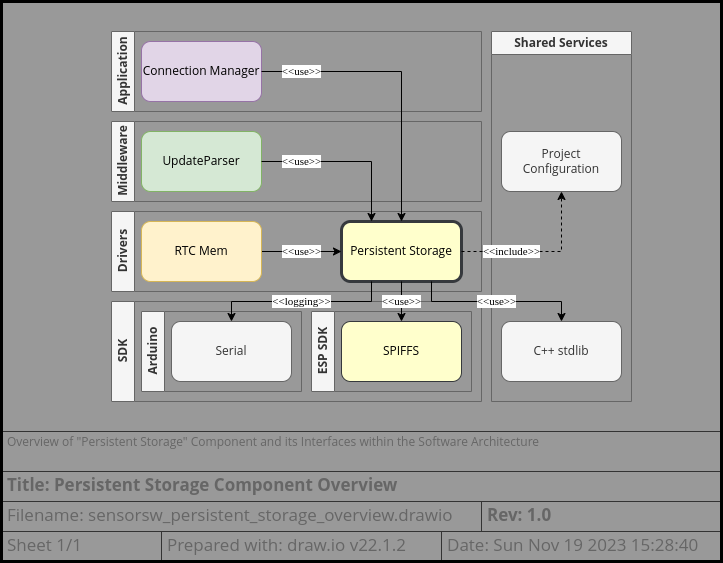
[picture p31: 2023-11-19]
doc/drawio/sensorsw_persistent_storage_overview.png

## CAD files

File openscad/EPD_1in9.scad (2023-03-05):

// Waveshare EPD_1in9 Segmented e-Paper Display
// Modeled from https://www.waveshare.com/w/upload/5/53/1.9inch_Segment_e-Paper_Specification.pdf

$fn=36;
FREECAD=1; //set to 1 for FreeCAD rendering, 0 for OpenSCAD preview

// Helpful Constants
THICKNESS = 1.2; //measured: DS value is 1.14
EPD_BG_H = 49.35;
EPD_BG_W = 32.11;
EPD_EPL_H = 43.75;
EPD_EPL_W = 29.11;
EPD_EPL_OFF = 1.5;
EPD_FPC_OFF_H = 0.81;
EPD_FPC_OFF_L = 20; //measured: DS doesn't indicate

FPC_W1 = 5.35; //width at bottom glass: measured - DS doesn't indicate
FPC_W2 = 4.5; //width at connector plastic
FPC_L = 16.25; //from bend to connector
FPC_H = 11.18; //from bottom glass to bend
FPC_T = 0.08; //kapton thickness
CON_L = 6; //connector plastic
CON_T = 0.3; //connector plastic thickness: includes FPC_T
FPC_FOLD_DIST = 0;
FPC_FOLD_THICKNESS = 2.5; //pretty much a guess: height of circuit board + EPD_FPC_OFF_H + a bitextra

EPD_COLOR_TOP = "white";
EPD_COLOR_BOT = "black";
SEG_COLOR_TOP = "black";
SEG_COLOR_BOT = "white";
FPC_COLOR = "orange";
FPC_CON_COLOR = "black";

SEG_UNIT_B = 1.1;
SEG_UNIT_S = SEG_UNIT_B / 1.6;
SEG_TALL_H = 4.95;
SEG_SHORT_H = SEG_TALL_H / 1.6;
SEG_LONG_W = 2.87;
SEG_THIN_W = SEG_LONG_W / 1.6;

// Helpful modules
module inset() {
    difference() {
        children(0);
        translate([0,0,-.1])
            scale([1,1,2])
                children([1:$children-1]);
    }
    children([1:$children-1]);
}

module segment(top_color=SEG_COLOR_TOP, bot_color=SEG_COLOR_BOT) {
    color(bot_color)
        scale([1,1,0.5])
            children();
    color(top_color)
        translate([0,0,THICKNESS/2])
            scale([1,1,0.5])
                children();    
}

module big_unit_seg()
    cube([SEG_UNIT_B, SEG_UNIT_B, THICKNESS]);

module small_unit_seg()
    cube([SEG_UNIT_S, SEG_UNIT_S, THICKNESS]);

module tall_seg()
    cube([SEG_TALL_H, SEG_UNIT_B, THICKNESS]);

module short_seg()
    cube([SEG_SHORT_H, SEG_UNIT_S, THICKNESS]);

module long_seg()
    cube([SEG_UNIT_B, SEG_LONG_W, THICKNESS]);

module thin_seg()
    cube([SEG_UNIT_S, SEG_THIN_W, THICKNESS]);

module corner_seg(r, unit_size) {
    translate([unit_size/2, unit_size/2])
    rotate([0,0,r*90])
    hull() {
        translate([-unit_size/6,-unit_size/6])
            cylinder(h=THICKNESS, d=unit_size*2/3);
        cube([unit_size/2, unit_size/2, THICKNESS]);
        translate([-unit_size/2, 0])
            cube([unit_size/2, unit_size/2, THICKNESS]);
        translate([0, -unit_size/2])
            cube([unit_size/2, unit_size/2, THICKNESS]);
    }
}

module big_corner_seg(rotation)
    corner_seg(rotation, SEG_UNIT_B);

module small_corner_seg(rotation)
    corner_seg(rotation, SEG_UNIT_S);

module decimal_seg() {
    translate([SEG_UNIT_B/2, SEG_UNIT_B/2])
    hull() {
        translate([-SEG_UNIT_B/6,-SEG_UNIT_B/6])
            cylinder(h=THICKNESS, d=SEG_UNIT_B*2/3);
        translate([SEG_UNIT_B/6,-SEG_UNIT_B/6])
            cylinder(h=THICKNESS, d=SEG_UNIT_B*2/3);
        translate([-SEG_UNIT_B/6, SEG_UNIT_B/6])
            cylinder(h=THICKNESS, d=SEG_UNIT_B*2/3);
        translate([SEG_UNIT_B/6, SEG_UNIT_B/6])
            cylinder(h=THICKNESS, d=SEG_UNIT_B*2/3);
    }
}

// Main
inset() { //EPD inset in bottom glass
    color(EPD_COLOR_TOP)
        cube([EPD_BG_H, EPD_BG_W, THICKNESS]);

    inset() { //segments inset in EPD
        segment(EPD_COLOR_TOP, EPD_COLOR_BOT)
            translate([EPD_EPL_OFF, EPD_EPL_OFF])
                cube([EPD_EPL_H, EPD_EPL_W, THICKNESS]);

        // byte 0 bit 0
        segment()
            translate([6.12, 3.75]) big_corner_seg(0);

        // byte 0 bit 1
        segment()
            translate([7.45, 3.75]) tall_seg();

        // byte 0 bit 2
        segment()
            translate([12.62, 3.75]) big_unit_seg();

        // byte 0 bit 3
        segment()
            translate([13.95, 3.75]) tall_seg();

        // byte 0 bit 4
        segment()
            translate([19.12, 3.75]) big_corner_seg(1);

        // byte 1 bit 0
        segment()
            translate([6.12, 6.35]) big_corner_seg(0);

        // byte 1 bit 1
        segment()
            translate([7.45, 6.35]) tall_seg();

        // byte 1 bit 2
        segment()
            translate([12.62, 6.35]) big_unit_seg();

        // byte 1 bit 3
        segment()
            translate([13.95, 6.35]) tall_seg();

        // byte 1 bit 4
        segment()
            translate([19.12, 6.35]) big_corner_seg(1);

        // byte 1 bit 5
        segment()
            translate([6.12, 7.65]) long_seg();

        // byte 1 bit 6
        segment()
            translate([12.62, 7.65]) long_seg();

        // byte 1 bit 7
        segment()
            translate([19.12, 7.65]) long_seg();

        // byte 2 bit 0
        segment()
            translate([6.12, 10.75]) big_corner_seg(3);

        // byte 2 bit 1
        segment()
            translate([7.45, 10.75]) tall_seg();

        // byte 2 bit 2
        segment()
            translate([12.62, 10.75]) big_unit_seg();

        // byte 2 bit 3
        segment()
            translate([13.95, 10.75]) tall_seg();

        // byte 2 bit 4
        segment()
            translate([19.12, 10.75]) big_corner_seg(2);

        // byte 3 bit 0
        segment()
            translate([6.12, 13.35]) big_corner_seg(0);

        // byte 3 bit 1
        segment()
            translate([7.45, 13.35]) tall_seg();

        // byte 3 bit 2
        segment()
            translate([12.62, 13.35]) big_unit_seg();

        // byte 3 bit 3
        segment()
            translate([13.95, 13.35]) tall_seg();

        // byte 3 bit 4
        segment()
            translate([19.12, 13.35]) big_corner_seg(1);

        // byte 3 bit 5
        segment()
            translate([6.12, 14.68]) long_seg();

        // byte 3 bit 6
        segment()
            translate([12.65, 14.68]) long_seg();

        // byte 3 bit 7
        segment()
            translate([19.12, 14.68]) long_seg();

        // byte 4 bit 0
        segment()
            translate([6.12, 17.8]) big_corner_seg(3);

        // byte 4 bit 1
        segment()
            translate([7.45, 17.8]) tall_seg();

        // byte 4 bit 2
        segment()
            translate([12.62, 17.8]) big_unit_seg();

        // byte 4 bit 3
        segment()
            translate([13.95, 17.8]) tall_seg();

        // byte 4 bit 4
        segment()
            translate([19.12, 17.8]) big_corner_seg(2);

        // byte 4 bit 5
        segment()
            translate([19.12, 20.13]) decimal_seg();

        // byte 5 bit 0
        segment()
            translate([25.07, 6.35]) big_corner_seg(0);

        // byte 5 bit 1
        segment()
            translate([26.4, 6.35]) tall_seg();

        // byte 5 bit 2
        segment()
            translate([31.6, 6.35]) big_unit_seg();

        // byte 5 bit 3
        segment()
            translate([32.9, 6.35]) tall_seg();

        // byte 5 bit 4
        segment()
            translate([38.07, 6.35]) big_corner_seg(1);

        // byte 5 bit 5
        segment()
            translate([25.07, 7.65]) long_seg();

        // byte 5 bit 6
        segment()
            translate([31.6, 7.65]) long_seg();

        // byte 5 bit 7
        segment()
            translate([38.07, 7.65]) long_seg();

        // byte 6 bit 0
        segment()
            translate([25.07, 10.75]) big_corner_seg(3);

        // byte 6 bit 1
        segment()
            translate([26.4, 10.75]) tall_seg();

        // byte 6 bit 2
        segment()
            translate([31.6, 10.7]) big_unit_seg();

        // byte 6 bit 3
        segment()
            translate([32.9, 10.75]) tall_seg();

        // byte 6 bit 4
        segment()
            translate([38.07, 10.75]) big_corner_seg(2);

        // byte 7 bit 0
        segment()
            translate([25.07, 13.35]) big_corner_seg(0);

        // byte 7 bit 1
        segment()
            translate([26.4, 13.35]) tall_seg();

        // byte 7 bit 2
        segment()
            translate([31.6, 13.35]) big_unit_seg();

        // byte 7 bit 3
        segment()
            translate([32.9, 13.35]) tall_seg();

        // byte 7 bit 4
        segment()
            translate([38.07, 13.35]) big_corner_seg(1);

        // byte 7 bit 5
        segment()
            translate([25.07, 14.68]) long_seg();

        // byte 7 bit 6
        segment()
            translate([31.6, 14.68]) long_seg();

        // byte 7 bit 7
        segment()
            translate([38.07, 14.68]) long_seg();

        // byte 8 bit 0
        segment()
            translate([25.07, 17.8]) big_corner_seg(3);

        // byte 8 bit 1
        segment()
            translate([26.4, 17.8]) tall_seg();

        // byte 8 bit 2
        segment()
            translate([31.6, 17.8]) big_unit_seg();

        // byte 8 bit 3
        segment()
            translate([32.9, 17.8]) tall_seg();

        // byte 8 bit 4
        segment()
            translate([38.07, 17.8]) big_corner_seg(2);
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

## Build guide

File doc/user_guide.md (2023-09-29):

# User Guide
This outline is currently a work-in-progress.

## Toolchain Installation
### Minimal
### Arduino

## Sensor Setup
### Sensor Stackup/Compatibility
### Battery Installation/USB Power
### Programming
- flash.sh
- tethered/battery FW
### Configuration
- WiFi Manager
- Sensor Names (see aliases below)
- Server address (see below)
### Debugging (see below)

## Server Setup
### Installation
- raspberry pi notes?
### Node-red configuration
- flows installation
- link to firmware directory
- SOH monitoring setup
### Influx DB Configuration
### Grafana Configuration
- Dashboard Configuration
- Sensor Aliases (see names above)
- Dewpoint Example
### Firewall Configuration
- Node-red
- Grafana
### Debugging (see below)

## Sensor Calibration
- Potential Methods
- VCC calibration firmware
- WiFi Manager
- OTA

## OTA Updates
### Firmware
- git pull
- manaual copy
### Sensor Configuration
- file creation and name/contents
- server address example

## Sensor Debugging
### Monitoring
- monitor.sh
- arduino
### Arduino Programming
- developer mode
### Common Problems
- corosion
- battery contacts
- wifi credentials lost
- wireless AP (see node-red monitoring above)

## Server Debugging
### Node-red Monitoring
### Common Problems
- firewall
- DNS

## Waveshare 1.9 inch. E-Paper Display
### Sourcing Options
- AliExpress Link
- Full Module vs Display Only
### Custom Wiring for Module
- Show wiring harness for the full module to attach to D1 Mini
### Custom Display Board
- PCB Ordering from OSHPark
- Stencil Ordering from OSHStencils
- Digikey Bill of Materials
- Notes
  - Stencil Thickness
  - FFC Connector Difficulty (suggest hotplate rather than hot air)

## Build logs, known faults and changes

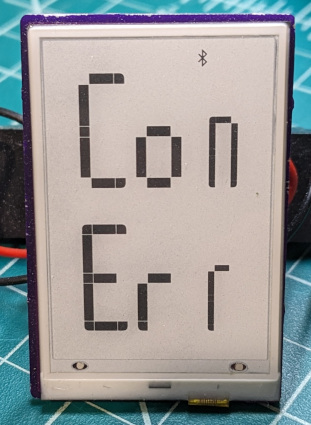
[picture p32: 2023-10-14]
doc/photos/EPD_1in9_connection_failure.jpg

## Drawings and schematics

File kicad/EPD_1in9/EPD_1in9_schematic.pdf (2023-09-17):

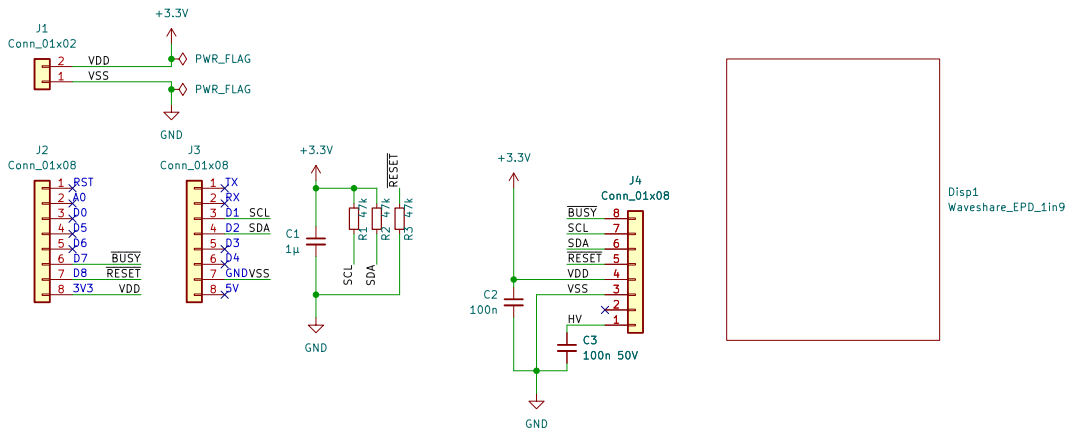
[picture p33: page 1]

~{BUSY} SCL ~{RESET} SDA

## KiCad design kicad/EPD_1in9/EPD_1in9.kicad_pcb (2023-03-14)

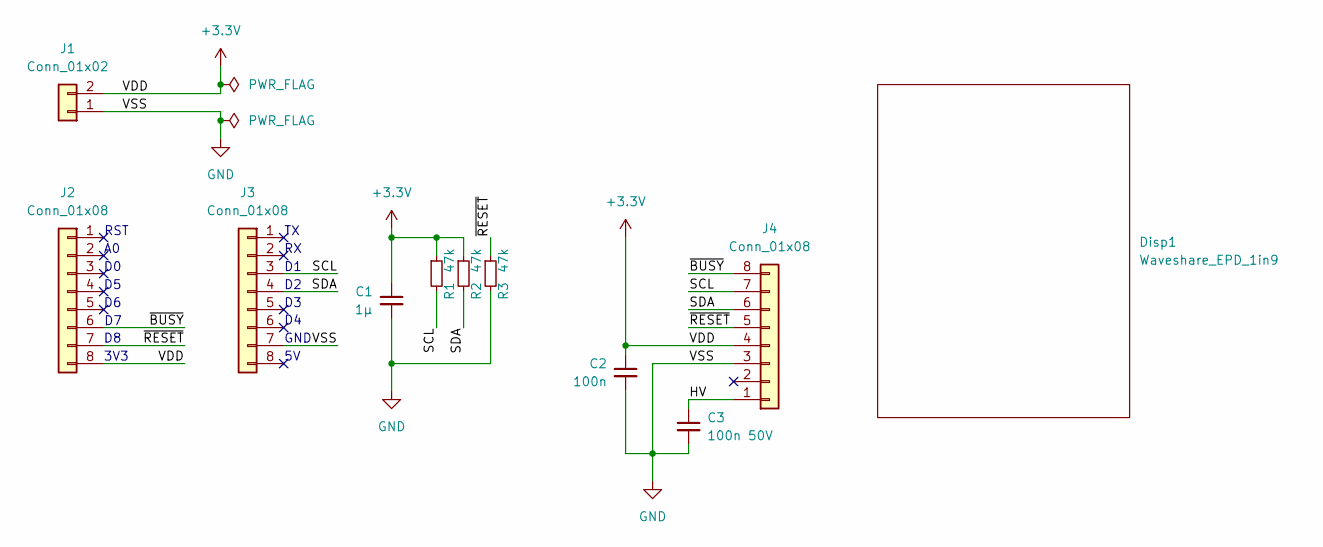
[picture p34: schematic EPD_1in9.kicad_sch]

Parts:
C1: 1μ; C_0805_2012Metric_Pad1.18x1.45mm_HandSolder
C2: 100n; C_1206_3216Metric_Pad1.33x1.80mm_HandSolder
C3: 100n 50V; C_1206_3216Metric_Pad1.33x1.80mm_HandSolder
Disp1: Waveshare_EPD_1in9
J1: Conn_01x02; PinHeader_1x02_P2.54mm_Vertical_SMD_Pin1Right
J2, J3: Conn_01x08; PinHeader_1x08_P2.54mm_Vertical_SMD_Pin1Right
J4: Conn_01x08; CivLux_CF3527S_1x08-1MP_P0.50mm_Horizontal
R1, R2, R3: 47k; R_1206_3216Metric_Pad1.30x1.75mm_HandSolder

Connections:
+3.3V: C1.1, C2.1, J1.2, J2.8, J4.4, R1.1, R2.1
/HV: C3.1, J4.1
/SCL: J3.3, J4.7, R1.2
/SDA: J3.4, J4.6, R2.2
/~BUSY: J2.6, J4.8
/~RESET: J2.7, J4.5, R3.1
GND: C1.2, C2.2, C3.2, J1.1, J3.7, J4.3, R3.2

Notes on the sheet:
RST
GND
3V3

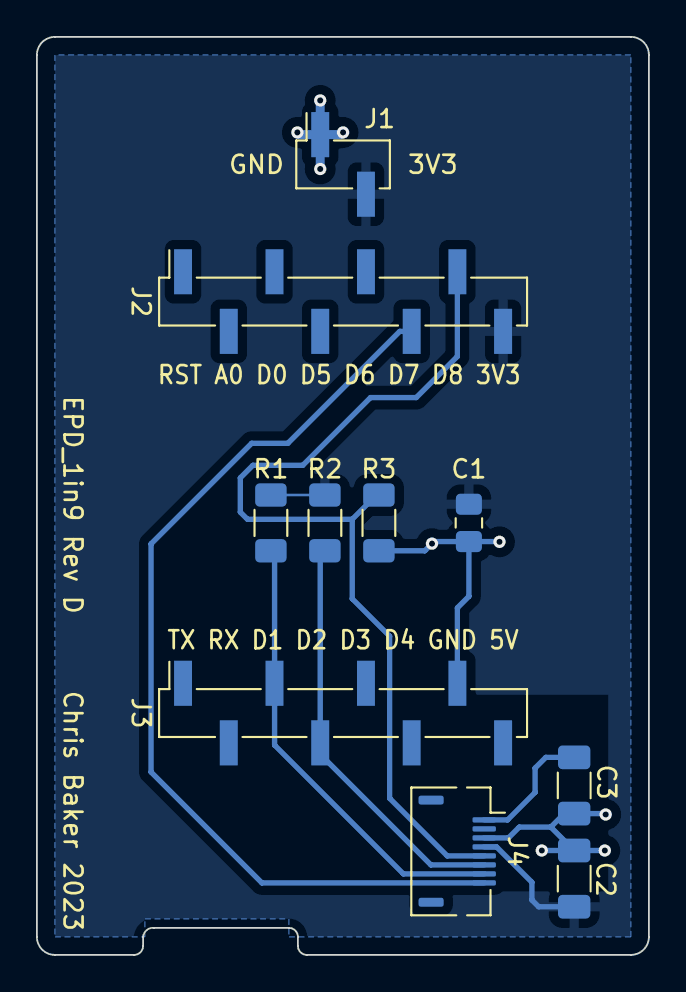
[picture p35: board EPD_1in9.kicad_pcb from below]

Board: 2 copper layers, 34.0 x 51.0 mm, 11 parts (10 on the bottom side), 7 nets.

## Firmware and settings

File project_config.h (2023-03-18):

#ifndef _PROJECT_CONFIG_H_
#define _PROJECT_CONFIG_H_

/* Global Configurations */
#define VCC_CAL_MODE            (0)
#if VCC_CAL_MODE
#define DEVELOPMENT_BUILD       (1)
#define TETHERED_MODE           (1)
#else
#define DEVELOPMENT_BUILD       (0)
#define TETHERED_MODE           (0)
#endif

#define SERIAL_SPEED            (115200)
#define CONFIG_SERVER_MAX_TIME  (120 /* seconds without client */)
#define BUILD_UNIQUE_ID         (__TIME__[3]*1000+__TIME__[4]*100+__TIME__[6]*10+__TIME__[7])
#define PREINIT_MAGIC           (0xAA559876 ^ BUILD_UNIQUE_ID)
#define SHT30_ADDR              (0x45)
#define REPORT_RESPONSE_TIMEOUT (2000)
#define WIFI_CONNECT_TIMEOUT    (30000)
#define LOW_BATTERY_VOLTAGE     (3.14f)
#define CRIT_BATTERY_VOLTAGE    (2.70f)
/* num of connection failures after which the next failure will result in
   displaying the connection error message on the EPD_1in9 display
   3 seems reasonable, since it will have been 7xSLEEP_TIME_US since we were
   ready to transmit and the next display update will come in 8xSLEEP_TIME_US
   at which point the current display will be very out-of-date */
#define DISP_CONNECT_FAIL_COUNT (3)
/* since ESP.deepSleepMax() doesn't work properly, just hard-code a value
   that will work over a typical temperature range and clamp any sleep
   period to this value */
#define MAX_ESP_SLEEP_TIME_MS   (9180000ULL)

#if TETHERED_MODE
  #define PPD42_PIN_DET         (D5)
  #define PPD42_PIN_1_0         (D7)
  #define PPD42_PIN_2_5         (D6)
  #define FIRMWARE_NAME         "iotsp-tethered"
#else
  #define FIRMWARE_NAME         "iotsp-battery"
#endif

#define EPD_FULL_REFRESH_TIME_MS (180000)
#define EPD_BUSY_PIN          (D7)
#define EPD_RST_PIN           (D8 /*note: remove R9 pullup on waveshare board */)
#define EPD_RST_POLARITY      (0)
#define EPD_FAHRENHEIT        (1)

#if DEVELOPMENT_BUILD
  #define EXTRA_DEBUG           (1)
  #define DISABLE_FW_UPDATE     (1)
  #define SIMULATE_GOOD_CONNECTION (1)
  #define SLEEP_TIME_US         (10000000ULL)
  #define NUM_STORAGE_SLOTS     (27)
  #if TETHERED_MODE
    #define HIGH_WATER_SLOT     (1)
  #else
    #define HIGH_WATER_SLOT     (17)
  #endif
#else
  #define EXTRA_DEBUG           (0)
  #define DISABLE_FW_UPDATE     (0)
  #define SIMULATE_GOOD_CONNECTION (0)
  #define SLEEP_TIME_US         (60000000ULL)
  #define NUM_STORAGE_SLOTS     (117)
  #if TETHERED_MODE
    #define HIGH_WATER_SLOT     (1)
  #else
    #define HIGH_WATER_SLOT     (NUM_STORAGE_SLOTS-15)
  #endif
#endif

//persistent storage file names
#define PERSISTENT_NODE_NAME        "node_name"
#define PERSISTENT_REPORT_HOST_NAME "report_host_name"
#define PERSISTENT_REPORT_HOST_PORT "report_host_port"
#define PERSISTENT_CLOCK_CALIB      "clock_drift_calibration"
#define PERSISTENT_TEMP_CALIB       "temperature_calibration"
#define PERSISTENT_HUMIDITY_CALIB   "humidity_calibration"
#define PERSISTENT_PRESSURE_CALIB   "pressure_calibration"
#define PERSISTENT_BATTERY_CALIB    "battery_calibration"
#define PERSISTENT_SLEEP_TIME_MS    "sleep_time_ms"
#define PERSISTENT_HIGH_WATER_SLOT  "high_water_slot"

//persistent storage default values
#define DEFAULT_NODE_BASE_NAME      "iotsp-"
#define DEFAULT_REPORT_HOST_NAME    "192.168.0.1"
#define DEFAULT_REPORT_HOST_PORT    (2880)
#define DEFAULT_SLEEP_CLOCK_ADJ     (120)
#define DEFAULT_TEMP_CALIB          (0.0f)
#define DEFAULT_HUMIDITY_CALIB      (0.0f)
#define DEFAULT_PRESSURE_CALIB      (0.0f)
#define DEFAULT_BATTERY_CALIB       (0.0f)
#define DEFAULT_SLEEP_TIME_MS       (SLEEP_TIME_US/1000)
#define DEFAULT_HIGH_WATER_SLOT     (HIGH_WATER_SLOT)

#endif /* _PROJECT_CONFIG_H_ */

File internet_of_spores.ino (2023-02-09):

#include "project_config.h"

#include <Arduino.h>
#include <core_esp8266_waveform.h>
#include <Esp.h>
#include <user_interface.h>

#include "connectivity.h"
#include "EPD_1in9.h"
#include "rtc_mem.h"
#include "sensors.h"


/* Global Data Structures */
const uint32_t preinit_magic = PREINIT_MAGIC;

/* Functions */
#if !TETHERED_MODE
void preinit(void)
{
  // Global WiFi constructors are not called yet
  // (global class instances like WiFi, Serial... are not yet initialized)..
  // No global object methods or C++ exceptions can be called in here!

  connectivity_preinit();
}
#endif

// Read from all of the attached sensors and store the readings
// Read some of the sensors twice to get an average value
void take_readings(void)
#if VCC_CAL_MODE
{
  for (int i=0; i<9; i++) {
    read_vcc(false);
    delay(100);
  }
  read_vcc(true);

  store_uptime();
}
#else /* VCC_CAL_MODE */
{
  bool sht30_ok;
#if TETHERED_MODE
  bool bat_ok = true;
#else
  flags_time_t *flags = (flags_time_t*) &rtc_mem[RTC_MEM_FLAGS_TIME];
  bool bat_ok = (0 == (flags->flags & FLAG_BIT_CONNECT_NEXT_WAKE));
#endif

  if (bat_ok)
    read_vcc(false);

#if TETHERED_MODE
  // check the detection pin before reading the partical sensor since it shares
  // DIO pins with the 1.9" EPD
  if (!digitalRead(PPD42_PIN_DET))
    read_ppd42();
#endif

  //read temp/humidity from SHT30
  sht30_ok = read_sht30(false);

  //read temp/humidity from HP303B
  read_hp303b(!sht30_ok);

  if (sht30_ok)
    read_sht30(true);

  if (bat_ok)
    read_vcc(true);

  store_uptime();
}
#endif /* VCC_CAL_MODE */

void disp_readings(bool connectivity=false, bool connection_error=false)
{
  float temp;
  float batt;
  float *rtc_float_ptr;
  float humidity;
  flags_time_t *flags = (flags_time_t*) &rtc_mem[RTC_MEM_FLAGS_TIME];
  boot_count_t *boot_count = (boot_count_t*) &rtc_mem[RTC_MEM_BOOT_COUNT];
  sleep_params_t *sleep_params = (sleep_params_t*) &rtc_mem[RTC_MEM_SLEEP_PARAMS];
  uint8_t res = 0;
  bool low_battery = false;
  bool crit_battery = false;

#if TETHERED_MODE
  // check the PPD42 detection pin before initializing the 1.9" EPD display
  // since they share DIO pins
  if (!digitalRead(PPD42_PIN_DET))
    return;
#endif

  // use the current temperature to initialize some display timings
  temp=get_temp();
  rtc_float_ptr = (float*)&rtc_mem[RTC_MEM_TEMP_CAL];
  temp += *rtc_float_ptr;
  if ((!isnan(temp)) && (temp >= 0))
    EPD_1in9_Set_Temp(int(temp));

  // check the current battery voltage and display an error message or avoid updating the display
  batt=get_battery();
  rtc_float_ptr = (float*)&rtc_mem[RTC_MEM_BATTERY_CAL];
  batt += *rtc_float_ptr;

  if (batt < LOW_BATTERY_VOLTAGE)
    low_battery = true;

  if (flags->flags & FLAG_BIT_LOW_BATTERY)
    res = 1; // battery voltage was already critical, don't initialize display

  if (batt < CRIT_BATTERY_VOLTAGE) {
    crit_battery = true;
    flags->flags |= FLAG_BIT_LOW_BATTERY;
  } else if (!isnan(batt)) {
    crit_battery = false;
    flags->flags &= ~FLAG_BIT_LOW_BATTERY;
  }

  // if temperature is below 0 celsius, or if the battery voltage is
  // already critical, don't initialize the display
  if ((0 != res) || (temp < 0)) {
    res = 1;
  } else {
    EPD_1in9_GPIOInit();
    res = EPD_1in9_init();
  }

  if (0 != res) {
    digitalWrite(EPD_RST_PIN, EPD_RST_POLARITY);
    return;
  }
  else
  {
    uint64_t templ = boot_count->epd_partial_refresh_count * sleep_params->sleep_time_ms;

    //set to 0 if the time since last full refresh is > 3 minutes
    if (templ >= EPD_FULL_REFRESH_TIME_MS)
      boot_count->epd_partial_refresh_count = 0;

    //use 0 as the trigger for a full refresh so that we do this on initial power up
    //as well as if the refresh counter rolls over from 255 -> 0
    if (boot_count->epd_partial_refresh_count == 0)
      EPD_1in9_Clear_Screen();

    //increment the refresh count after making decision
    //so that we can do a full refresh on initial power up
    boot_count->epd_partial_refresh_count++;
  }

#if EPD_FAHRENHEIT
  temp = (temp * 9/5)+32.0;
#endif
  humidity=get_humidity();
  rtc_float_ptr = (float*)&rtc_mem[RTC_MEM_HUMIDITY_CAL];
  humidity += *rtc_float_ptr;
  EPD_1in9_Easy_Write_Full_Screen(temp, humidity, EPD_FAHRENHEIT, connectivity, connection_error, low_battery, crit_battery);
  EPD_1in9_sleep();
}

bool check_upload_conditions(void)
{
  flags_time_t *flags = (flags_time_t*) &rtc_mem[RTC_MEM_FLAGS_TIME];
  sleep_params_t *sleep_params = (sleep_params_t*) &rtc_mem[RTC_MEM_SLEEP_PARAMS];
  boot_count_t *rtc_boot_count = (boot_count_t*) &rtc_mem[RTC_MEM_BOOT_COUNT];
  uint32_t boot_count = rtc_boot_count->boot_count;

  /*
   * Normal upload condition:
   * If our number of collected readings is above the high water mark, then it
   * is time to start uploading (allowing for a couple of failed connections).
   * Extra conditions:
   * If our boot count is a power of 2 during the first few boots, then we will
   * do a special upload to get some early readings sent to the server.
   * (This way you won't have to wait for 30-45 minutes before the initial
   * readings come in.)
   */
  if (rtc_mem[RTC_MEM_NUM_READINGS] >= sleep_params->high_water_slot) {
    flags->flags |= FLAG_BIT_NORMAL_UPLOAD_COND;
    return true;
  }
  if ( (0 == (flags->flags & FLAG_BIT_NORMAL_UPLOAD_COND)) &&
    (0==(boot_count & (boot_count - 1))) )
    return true;

  return false;
}

#if TETHERED_MODE
void tethered_sleep(int64_t millis_offset, bool please_reboot)
{
  sleep_params_t *sleep_params = (sleep_params_t*) &rtc_mem[RTC_MEM_SLEEP_PARAMS];
  int64_t sleep_delta_ms = (int64_t)sleep_params->sleep_time_ms - ((int64_t)millis()-millis_offset);

#if EXTRA_DEBUG
  Serial.printf("[%llu] sleep_delta_ms=%lld\n", uptime(), sleep_delta_ms);
#endif
  if (sleep_delta_ms > 200LL)
    deep_sleep(sleep_delta_ms*1000);
  else if (please_reboot)
    deep_sleep(100);
  else
    save_rtc(); // it is probably still worth saving RTC mem in case of soft reset, etc.

  if (sleep_delta_ms > 0)
    delay(sleep_delta_ms);
}
#endif /* TETHERED_MODE */

#if !TETHERED_MODE
void battery_sleep(bool connect_failed=false)
{
  sleep_params_t *sleep_params = (sleep_params_t*) &rtc_mem[RTC_MEM_SLEEP_PARAMS];
  flags_time_t *flags = (flags_time_t*) &rtc_mem[RTC_MEM_FLAGS_TIME];
  uint64_t sleep_delta_ms = sleep_params->sleep_time_ms;

  connectivity_disable();

  if (connect_failed) {
    sleep_delta_ms <<= flags->fail_count;
    if (flags->fail_count < 6)
      flags->fail_count++;
#if EXTRA_DEBUG
    Serial.printf("[%llu] sleep_delta_ms=%lld\n", uptime(), sleep_delta_ms);
#endif
  } else {
    flags->fail_count = 0;
  }

  if (flags->flags & FLAG_BIT_LOW_BATTERY)
    sleep_delta_ms = MAX_ESP_SLEEP_TIME_MS; // battery voltage is critical, sleep forever

  deep_sleep(sleep_delta_ms*1000);
}
#endif /* !TETHERED_MODE */

void setup(void)
{
  bool rtc_config_valid = false;

  pinMode(LED_BUILTIN, INPUT);

  Serial.begin(SERIAL_SPEED);
  delay(2);
  Serial.println();

  sensors_init();
  rtc_config_valid = load_rtc_memory();

  // We can detect a "double press" of the reset button as a regular Ext Reset
  // This is because we spend most of our time asleep and a single press will
  // generally appear as a deep-sleep wakeup.
  // We will use this to enter the WiFi config mode.
  // However, we must ignore it on the first boot after reprogramming or inserting
  // the battery -- so only pay attention if the RTC memory checksum is OK.
  if ((ESP.getResetInfoPtr()->reason == REASON_EXT_SYS_RST) && rtc_config_valid) {
    pinMode(LED_BUILTIN, OUTPUT);
    startWaveform(LED_BUILTIN, 350000, 50000, 0);
    connectivity_init();
    enter_config_mode();
    stopWaveform(LED_BUILTIN);
    pinMode(LED_BUILTIN, INPUT);

#if !TETHERED_MODE
  battery_sleep();
#endif
  } else {
#if TETHERED_MODE
    // defer this if battery-powered
    connectivity_init();
#endif
  }
}

void loop(void)
{
  flags_time_t *flags = (flags_time_t*) &rtc_mem[RTC_MEM_FLAGS_TIME];
#if TETHERED_MODE
  unsigned long loop_start = millis();
#endif
  bool connect_failed = false;
  bool want_to_connect = false;

  take_readings();
  dump_readings();

#if !TETHERED_MODE
  if (0 != (flags->flags & FLAG_BIT_CONNECT_NEXT_WAKE))
    want_to_connect = true;
#else
  if (check_upload_conditions())
    want_to_connect = true;
#endif

  // display the readings on the EPD_1in9 display
  // but, if we are already showing the connection error message
  // don't bother updating the display until we are successful
  if (flags->fail_count <= DISP_CONNECT_FAIL_COUNT)
    disp_readings(want_to_connect);

  // is it time to connect and upload our readings?
  if (want_to_connect) {
    uint32_t num_readings = rtc_mem[RTC_MEM_NUM_READINGS];

#if !TETHERED_MODE
    //this is normally done in setup() but deferred in battery mode
    connectivity_init();
#endif

#if SIMULATE_GOOD_CONNECTION
    Serial.println("Simulating WiFi connection");
    Serial.println("Simulating upload");
    clear_readings();
    Serial.println("Upload OK");
#else
    if (connect_wifi())
      upload_readings();
#endif

    //we failed to make progress uploading readings
    //factor this into sleep time decisions
    if (rtc_mem[RTC_MEM_NUM_READINGS] == num_readings)
      connect_failed = true;

    // if we have failed the defined number of times, display a connection error message
    // on the EPD_1in9 display
    if (connect_failed && (flags->fail_count == DISP_CONNECT_FAIL_COUNT))
      disp_readings(true, true);

    // if we have succeeded, but are currently showing the connection error message
    // on the EPD_1in9 display, then clear it and show the actual readings
    if (!connect_failed && (flags->fail_count > DISP_CONNECT_FAIL_COUNT))
      disp_readings(false, false);
  }

#if !TETHERED_MODE
  if (!connect_failed) {
    if (check_upload_conditions()) {
      // we have collected enough readings, time to upload them
      // due to bugs/changes in deep sleep operation, the workaround is to do a
      // non-rf-disabled sleep and then transmit on the next wakeup
      flags->flags |= FLAG_BIT_CONNECT_NEXT_WAKE;
    } else {
      flags->flags &= ~FLAG_BIT_CONNECT_NEXT_WAKE;
    }
  }
#endif

#if TETHERED_MODE
  // in tethered mode, sleep time is more of a suggestion if other
  // activities don't take longer
  tethered_sleep(loop_start, connect_failed);
#else
  battery_sleep(connect_failed);
#endif
}

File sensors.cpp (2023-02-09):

#include "project_config.h"

#include <Arduino.h>
#include <Esp.h>
#include <LOLIN_HP303B.h>
#include <Wire.h>

#include "pulse2.h"
#include "rtc_mem.h"
#include "sensors.h"
#include "sht30.h"


/* Global Data Structures */
LOLIN_HP303B HP303BPressureSensor;
#if TETHERED_MODE
Pulse2 pulse;
#endif
static float gTemperature=NAN;
static float gHumidity=NAN;
static float gBattery=NAN;

/* Functions */
// setup sensors
void sensors_init(void)
{
  Wire.begin();

#if TETHERED_MODE
  pinMode(PPD42_PIN_DET, INPUT_PULLUP);
#endif
}

#if TETHERED_MODE
// read and store values from the PPD42 particle sensor
// this measurement is recommended to take 30 seconds (parameter)
// also the sensor requires a 3 minute warm-up time
// so only available in tethered mode
void read_ppd42(unsigned long sampletime_us)
{
  if (!digitalRead(PPD42_PIN_DET)) {
    unsigned long starttime_us = micros();
    unsigned long lpo10 = 0;
    unsigned long lpo25 = 0;
    unsigned long total;
    pinMode(PPD42_PIN_1_0, INPUT);
    pinMode(PPD42_PIN_2_5, INPUT);
    pulse.register_pin(PPD42_PIN_1_0, LOW);
    pulse.register_pin(PPD42_PIN_2_5, LOW);

    while ((total = micros() - starttime_us) < sampletime_us) {
      unsigned long duration;
      uint8_t pin;
      pin = pulse.watch(&duration, (sampletime_us-total));
      if (PULSE2_NO_PIN != pin) {
        if (PPD42_PIN_1_0 == pin)
          lpo10 += duration;
        if (PPD42_PIN_2_5 == pin)
          lpo25 += duration;
#if EXTRA_DEBUG
        //Serial.printf("%lu: pulse: %lu: %s\n", millis(), duration, (pin==PPD42_PIN_1_0)?"PIN10":"PIN25");
#endif
      }
    }

    {
      float ratio10;
      float ratio25;
      float concentration10;
      float concentration25;
      int32_t count10;
      int32_t count25;

      // percentage of sampletime_us where 1.0/2.5μm pin was pulsed low
      ratio10 = lpo10*(100.0/total);
      ratio25 = lpo25*(100.0/total);
      concentration10 = 1.1*pow(ratio10,3)-3.8*pow(ratio10,2)+520*ratio10;
      concentration25 = 1.1*pow(ratio25,3)-3.8*pow(ratio25,2)+520*ratio25;
      if (concentration10 > 0)
        count10=concentration10/10; // *100 /1000
      else
        count10 = 0;
      if (concentration25 > 0)
        count25=concentration25/10; // *100 /1000
      else
        count25 = 0;
      store_reading(SENSOR_PARTICLE_1_0, count10);
      store_reading(SENSOR_PARTICLE_2_5, count25);
#if EXTRA_DEBUG
      Serial.printf("Raw Particle Count >1.0μm: %d particles/cf\n", count10*1000);
      Serial.printf("Raw Particle Count >2.5μm: %d particles/cf\n", count25*1000);
#endif
    }

    pulse.unregister_pin(PPD42_PIN_1_0);
    pulse.unregister_pin(PPD42_PIN_2_5);
  }
}
#endif

// read and store values from the SHT30 temperature and humidity sensor
bool read_sht30(bool perform_store)
{
  static float temperature=0; // running total for averaging
  static float humidity=0;    // running total for averaging
  static unsigned int num_readings=0; // count for averaging
  sht30_data_t data;
  int ret;
  ret = sht30_get(SHT30_ADDR, SHT30_RPT_HIGH, &data);
  Serial.println();
  if (ret != 0) {
    Serial.print("Error Reading SHT30 ret=");
    Serial.println(ret);
    return false;
  } else {
    temperature += sht30_parse_temp_c(data);
    humidity += sht30_parse_humidity(data);
    num_readings++;

#if (EXTRA_DEBUG != 0)
    Serial.print("Raw Temperature: ");
    Serial.print(sht30_parse_temp_c(data), 3);
    Serial.print("°C (");
    Serial.print(sht30_parse_temp_f(data), 3);
    Serial.println("°F)");
    Serial.print("Raw Humidity: ");
    Serial.println(sht30_parse_humidity(data), 3);
#endif
  }

  if (perform_store && num_readings) {
    store_reading(SENSOR_TEMPERATURE, temperature/num_readings*1000.0 + 0.5);
    store_reading(SENSOR_HUMIDITY, humidity/num_readings*1000.0 + 0.5);
    gTemperature = temperature/num_readings;
    gHumidity = humidity/num_readings;
    temperature = 0;
    humidity = 0;
    num_readings = 0;
  }

  return true;
}

// read and store values from the HP303B barametric pressure sensor
bool read_hp303b(bool measure_temp)
{
  //OVERSAMPLING TABLE
  // Val | Time (ms) | Noise (counts)
  //   0 |      15.6 | 12
  //   1 |      17.6 | 6
  //   2 |      20.6 | 4
  //   3 |      25.5 | 3
  //   4 |      39.6 | 2
  //   5 |      65.6 | 2
  //   6 |     116.6 | 2
  //   7 |     218.7 | 1
  int16_t oversampling = 4;
  int16_t ret;
  int32_t pressure;

  // Call begin to initialize HP303BPressureSensor
  // The default address is 0x77 and does not need to be given.
  HP303BPressureSensor.begin();

  if (measure_temp) {
    int32_t temperature;
    //lets the HP303B perform a Single temperature measurement with the last (or standard) configuration
    //The result will be written to the paramerter temperature
    //ret = HP303BPressureSensor.measureTempOnce(temperature);
    //the commented line below does exactly the same as the one above, but you can also config the precision
    //oversampling can be a value from 0 to 7
    //the HP303B will perform 2^oversampling internal temperature measurements and combine them to one result with higher precision
    //measurements with higher precision take more time, consult datasheet for more information
    ret = HP303BPressureSensor.measureTempOnce(temperature, oversampling);

    if (ret != 0) {
      //Something went wrong.
      //Look at the library code for more information about return codes
      Serial.print("Error Reading HP303B (temperature) ret=");
      Serial.println(ret);
      return false;
    } else {
      store_reading(SENSOR_TEMPERATURE, temperature*1000);
      gTemperature = temperature;
#if (EXTRA_DEBUG != 0)
      Serial.print("Raw Temperature: ");
      Serial.print(temperature);
      Serial.print(" °C (");
      Serial.print(((float)temperature * 9/5)+32.0);
      Serial.println(" °F)");
#endif
    }
  }

  //Pressure measurement behaves like temperature measurement
  //ret = HP303BPressureSensor.measurePressureOnce(pressure);
  ret = HP303BPressureSensor.measurePressureOnce(pressure, oversampling);
  if (ret != 0) {
    //Something went wrong.
    //Look at the library code for more information about return codes
    Serial.print("Error Reading HP303B (pressure) ret=");
    Serial.println(ret);
    return false;
  } else {
    store_reading(SENSOR_PRESSURE, pressure);
#if (EXTRA_DEBUG != 0)
    Serial.print("Raw Pressure: ");
    Serial.print(pressure/1000.0, 3);
    Serial.print(" kPa (");
    Serial.print((float)pressure/3386.39);
    Serial.println(" in Hg)");
#endif
  }

  return true;
}

/* Set ADC mode to read VCC voltage level (battery) */
ADC_MODE(ADC_VCC)
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

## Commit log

2019-08-18 Add support for SHT30 temperature and humidity sensor
    Lots of cleanup and reorganization of the file.
    Added overall framework for storing multiple types of sensor readings
    in the RTC memory.
    Added readout of SHT30 temp/humidity sensor using Wemos library.
    I previously had to modify this library but it is very simplistic so
    I will likely remove the dependency and implemet the I2C transactions
    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
2019-08-27 Add support for Sharp GP2Y dust sensor
    Detects the presence of the ~5k pullup on the LED output pin.
    This requires an external 20k pulldown since the ESP8266 doesn't
    really support internal pulldowns.
    Performed some additional reorganization and increased the number
    of stored sensor readings to 60.
    The GP2Y library was at least available from the board manager
    but is probably not worth keeping as a dependency long-term.
    Will likely look for a better dust sensor anyway that has I2C.
    [internet_of_spores.ino]
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2019-09-01 Add support for measuring VCC voltage
    The ESP8266 only supports reading the VCC voltage if the ADC input is
    floating. This pretty much puts the nail in the coffin of the GP2Y dust
    sensor. Reading the battery level is much preferable.
    -removed the gp2y functionality
    -added sensor type for battery voltage
    -added read_vcc function to read and store the vcc voltage
2019-09-02 Enable IOTAppStory Config Mode
    Detects external resets outside of sleep mode (quick-ish pressing
    the reset button after boot) and uses that as a trigger to enter
    the configuration mode.
    I also discovered that this was corrupting the ring buffer and
    added the IAS RTC memory values to the enum so that we can avoid
    interfering.
    [internet_of_spores.ino]
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2019-09-22 Remove IOTAppStory
    Remove IOTAppStory usage with #ifdef IOTAPPSTORY.
    This was proving to be more cumbersome that it was worth.
    I was having to reimplement most of the features because it
    didn't quite do what I wanted out-of-the-box and it was also
    entering configuration mode way too easily and getting stuck
    there.
    Replaced it by adding a basic webserver in AP mode for to
    handle future WiFi configuration and STA mode with reconnect
    to upload measurements.
    Took the opportunity to refactor some of the connectivity
    functions.
    [internet_of_spores.ino]
2019-09-22 Add unique build identifier
    Define BUILD_UNIQUE_ID based on __TIME__ to serve as a unique
    build identifier. It should always be < 16-bits.
    Initial use for this is to detect when we upload new code so
    that the RTC memory can be invalidated.
    If the RTC memory is invalidated, use that as a sign to ignore
    the Ext Reset press since this also happens every time we
    upload new firmware and was often getting stuck in config mode.
    [internet_of_spores.ino]
2019-09-22 Cleanup: move configurations and typedefs into separate headers
    project_config.h - high level configuration #defines
    rtc_mem.h - structures and helper functions for working with
    the rtc memory
    sensors.h - typedefs and helper functions for working with
    the sensor peripherals
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2019-09-23 Cleanup: Fix unique build identifier
    After moving everything to different files, this value doesn't get
    updated on incremental builds.
    However, the .ino file seems to always get rebuilt, so I have defined
    it as a const uint32_t there.
    [internet_of_spores.ino, rtc_mem.cpp]
2019-09-23 Add basic persistent storage module
    Stores each configuration as a file in SPIFFS.
    On readback, if the file doesn't exist, the supplied
    default value will be returned.
    [persistent.cpp]
2019-09-23 Add configurable persistent parameters
    Add parameters to WiFi manager so that user can configure values
    during setup process.
    Previous value will be shown as a hint.
    User can leave the field blank to avoid changing it.
    Values will be stored in SPIFFS using the persistent storage
    module if they have been changed (non-empty value).
    [connectivity.cpp, internet_of_spores.ino, project_config.h]
2019-09-24 Add a nice blink pattern on the LED when in config mode
2019-09-26 Add OTA update capability
    Added a firmware version identifier to the json preamble that
    is sent to the report server with the sensor measurements.
    This version identifier is based on minutes/seconds at build-
    time. The report server will see if this matches the file that
    it has in its firmware directory. If there is no match, it will
    reply with an indication that a firmware update is available.
    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
2019-09-26 Remove final traces of IOTAppStory
    Now that OTA update is implemented there is no need to
    retain IOTAppStory #define option.
2019-09-26 firmware update: invalidate rtc memory
    If the firmware update begins in earnest the rtc user memory
    needs to be invalidated. I was relying on the detection of new
    firmware version to handle this on next boot, but if the update
    fails it does not get invalidated resulting in the (possibly
    corrupted) measurements being resent again immediately.
    [connectivity.cpp]
2019-09-26 Implement configurable clock calibration
    During deep sleep, there is significant drift of the clock due to
    temperature which makes it difficult to determine the offset to add to
    the uptime millis. This value is also likely to be different from one
    module to another and, especially, between manufacturers of D1-mini
    clones.
    Over longer periods of time, the value can be averaged out and the
    offset updated through the configuration portal.
    [connectivity.cpp, project_config.h, rtc_mem.cpp]
2019-09-26 Implement configurable sensor calibrations
    These cheap sensors tend to have wide variance so that, while they are
    precise, they are not always absolutely accurate. Additionally, they
    will tend to change over time.
    This becomes problematic when trying to compare several sensors against
    each other or against past previous readings.
    A calibration offset is thus applied to each sensor reading and this can
    be modified in the configuration portal so that periodic calibrations
    may be performed.
    At the very least all sensors can be brought to a single location and
    calibrated against each other. In other cases, they might be compared
    against a known measurement standard.
    Published NOAA readings shou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
    [connectivity.cpp, project_config.h, rtc_mem.cpp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]
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2019-09-28 Add influxdb batch output to node-red flows
    This is pretty brittle at the moment and can easily lock up
    node-red. The catch and status nodes don't provide any useful
    way to detect whether the data was written correctly.
    Hopefully, these items will get better in time...
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2019-10-09 Add State-of-Health monitoring for node-red
    Node-red seems to be quite unstable. Randomly (after a few
    hours or a few days), it will lock-up and stop accepting data
    from the sensor nodes. During this period the process shows
    100% CPU usage, but no other diagnostic activity.
    Add a flow that prints periodic messages to the log and a
    monitor script that will watch for these messages and restart
    node-red if they go absent for a few minutes.
2019-10-09 soh-monitor: add basic error report feature
    Sending ctrl-c will print the current error count.
    Sending again will kill the script unless it has been longer
    than the timeout period (45 seconds).
2019-10-10 Add development build flag
    -Uses shorter timings so that things happen quicker
    -Ignores firmware updates from the server
    [connectivity.cpp, project_config.h]
2019-10-11 Add some averaging to the sensor readings
    HP303B already has some averaging built-in.
    SHT30 is quite noisy, so take 3 samples ~100 ms apart.
    Might as well take two VCC readings while we are at it
    but that doesn't seem to be as noisy.
    [internet_of_spores.ino, sensors.cpp]
2019-10-11 Track number of readings transmitted
    Add ability to return the number of readings transmitted and
    only clear that many readings.
    Currently still transmitting all readings in one batch, but
    this will be changed soon.
2019-10-12 Robustness: implement v2 protocol
    Implemented v2 of the TCP protocol for transmitting readings to
    node-red. Incremented the version value in the json string and
    created additional flows in node-red to separately parse the
    new message format.
    For robustness, it breaks up the json message into small batches
    rather than sending all of the measurements together.
    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
2019-10-13 upload_readings: only read PS files once
    Now that the upload is broken up into several transmit batches,
    the persistent storage files are being needlessly read many
    times over.
    Read the values once and pass them to the transmit function as
    an array.
    [connectivity.cpp]
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2019-10-29 Initial implementation of tethered mode
    This is a non-battery-powered mode so conserving energy is less of a
    priority. Consequenty, skip deep-sleep if our readings took too long
    and keep the RF section powered for faster reconnect.
    Additionally, there are now two different firmware builds, so provide
    different filenames that will be used during OTA update process.
    [connectivity.cpp, internet_of_spores.ino, project_config.h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]
2019-11-03 Tethered: fix deep sleep time calculation
    The casting was a bit off and ended up with an ~UINT_MAX instead of a
    negative int64.
    After skipping the sleep, millis() was always going to be too large to
    ever sleep again, so subtract the loop start time to make the
    calculation relevant.
    [internet_of_spores.ino, project_config.h]
2019-11-03 Tethered: fix uptime calculation when not sleeping
    When we don't enter deep sleep, the millis value is not reset, but we
    do keep using the stored value as the basis for our uptime calculation.
    This leads to geometric growth in the uptime value as the millis value
    is compounded with each call to save_rtc().
    It is still useful to store the incremented uptime in RTC mem in case
    of a warm reset. So, we can't just skip this step in tethered mode.
    Instead save the old timestruct value and restore it after writing the
    RTC user memory. If we get a warm reset, a reasonably up-to-date value
    will exist in RTC memory. If we continue running without sleeping, the
    original uptime value from the last res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
    [rtc_mem.cpp]
2019-11-03 Tethered: reset module if WiFi connection fails
    It seems possible to get into a condition where WiFi can't connect and
    a warm reboot is needed to fix it. My hypothesis is that something
    changed in the AP config and the firmware doesn't know how to deal with
    this and keeps trying to use the old values.
    If the connection fails ask for a short deep_sleep to trigger a reboot.
    Reconnect seems to work after this.
    [internet_of_spores.ino]
2019-11-03 Battery: increase sleep time to 30s
    Tweak some of the other timing parameters for development mode as well.
2019-11-03 Battery: store timestamp using only 1 slot
    Convert timestamp from using 2 24-bit sensor slots to just a single
    slot by encoding it as an offset from a stored 32-bit base time.
    The base time stores 256 ms ticks so that 40 bits of uptime can be
    stored in a single 32-bit RTC slot.
    When uploading readings to the server (or dumping them to the console)
    the ms offset is added to the base ticks count to recreate the original
    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
2019-11-10 ppd42: fix typo swapping 1.0/2.5µm pins
    [sensors.cpp]
2019-11-11 PPD42: avoid crash in interrupt handler
    It seems that the interrupt handler being triggered while reading from
    the SPIFFS causes some kind of crash -- looks like null pointer
    dereference in functional.
    It looks like unregistering the interrupt handler during this period
    will resolve the problem.
    [sensors.cpp]
2019-11-11 Tethered: reset averaging on store
    Was relying on deep_sleep to reset these variables before.
    [sensors.cpp]
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2019-11-17 Battery: increase sleep time when upload fails
    Increase the sleep time geometrically (up to 2^6 times) as long as
    uploading the readings is failing to make progress.
    In practice this should result in sleeping for as long as connectivity
    has been unavailable -- up to 32 minutes. Power consumption should drop
    equivalently and could approach 64x lower consumption for long outages.
    [connectivity.cpp, internet_of_spores.ino, rtc_mem.cpp]
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2019-11-23 PPD42: invert detect pin so INPUT_PULLUP can be used
    [sensors.cpp]
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2019-11-25 node-red: fix bug in error flows
    During an error condition, the firmware version is missing from the
    msg and this causes a recursive error.
2019-11-25 Revert "connectivity: ensure disconnect when turning WiFi off"
    This reverts commit 91d2139d507f9fcafd8f78a356ade01221aee3a0.
    There seems to be some problem with this disconnect process and
    the stored WiFi credentials are completely lost. Haven't really
    been able to debug it completely.
    [connectivity.cpp]
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2019-11-30 config portal: fix connectivity bug
    The WiFiManager config portal calls WiFi.disconnect(), but this is
    resulting in the SSID/password being reset and the re-connection fails.
    This is the same bug as the previously reverted commit.
    It seems that WiFi.disconnect() just loses its settings if called while
    in WIFI_STA mode...
    [connectivity.cpp]
2019-11-30 persistent: treat " " same as empty file
    The config portal doesn't have a way to differentiate between keeping
    the current setting and an empty string.
    This allows a single space to be used to reset the config to its default
    values.
    [persistent.cpp]
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2019-12-25 connectivity: flush client buffer between commands
    The old behavior of the WiFiClient seemed to mask the effect when some
    partial data was left in the client receive buffer between transmitted
    messages.
    In particular, when requesting several calibration update files in a
    row, the left over null byte from the previous message was being left
    in the buffer resulting in the next request getting a null string as
    the first response it saw.
    Refactor the code to use a standard send_command() function that will
    flush the Tx and Rx buffers, transmit the command, and verify the
    transmit length is correct.
    [connectivity.cpp]
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2023-01-15 Remove dynamic WiFi power adjustment
    This probably causes more problems and battery drain than it
    saves. The recommendation is to use 17.5 dBm as there could be
    additional noise above that. Lower power settings might conserve
    some battery, but they might also cause connections to take
    longer.
    [connectivity.cpp, rtc_mem.cpp]
2023-01-16 Add support for v3.0.2 of esplib
    There is some new bug in the WiFi STA connection when
    trying to connect after a deep sleep with RF disabled.
    The workaround seems to be to schedule a sleep with
    RF enabled for the next boot before trying to connect
    again.
    [internet_of_spores.ino, project_config.h, rtc_mem.cpp]
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2023-02-02 Don't measure battery voltage when waking with modem enabled
    It seems like this pulls down the ADC reference by about .3 volts.
    It doesn't disturbe the average too much, but my grafana setup tends to
    use the last reading for its dashboard and the battery constantly appears
    to be nearly dead.
    [internet_of_spores.ino]
2023-02-02 Fix issue with custom configs in WiFiManager
    The custom configurations aren't saving in WiFiManager unless it gets an
    updated SSID and is able to connect. In fact, it will not even exit the
    configuration without a new SSID.
    There is a new configuration option to restore the old behavior where it
    exits the configurator any time the user saves the settings. However,
    this will still typically fail to connect and return a failure.
    Change to providing a callback function to be alerted when the custom
    configs have been updated so that they can be stored regardless of the
    connection/configuration status.
    [connectivity.cpp]
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2023-02-04 EPD_1in9: Handle missing temp/humidity
    Show "--" on the display if temp or humidity value are not provided.
    Check is performed using isnan() and value for temp and humidity are
    initialized to NAN unless populated from a sensor.
    [EPD_1in9.cpp]
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2023-02-04 EPD_1in9: Add function to show connection error
    Add a flag to override the normal temp/humidity display with text
    that says "Con Err".
    [EPD_1in9.cpp, internet_of_spores.ino]
2023-02-04 EPD_1in9: Add logic to show connection error
    After DISP_CONNECT_FAIL_COUNT failed connection attempts (e.g. 3), the
    next failure will result in a connection error message on the display.
    This seems reasonable, since it will have been 7xSLEEP_TIME_US since we
    were ready to transmit and the next display update will come in
    8xSLEEP_TIME_US at which point the current display will be very
    out-of-date.
    [internet_of_spores.ino, project_config.h]
2023-02-09 Config: Add configurable sleep time and upload threshold
    Add configurable parameters to the WiFiManager to let the user change
    the default sleep time between measurements and set the high-water
    threshold at which point the WiFi upload will be attempted.
    The maximum sleep time reported by ESP.deepSleepMax() seems to be
    completely bogus. Through trial and error the maximum sleep time seems
    to be just over 3 hours.
    [connectivity.cpp, internet_of_spores.ino, project_config.h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]
2023-02-09 persistent: Add better error handling to persistent_read
    Use strtol/strtof instead of atol/atof for reads that return a value
    rather than a string.
    This allows better detection of invalid values stored in the persistent
    filesystem and returns the default_value.
    [persistent.cpp]
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2023-02-09 EPD_1in9: Make reset pin polarity configurable
    Experimenting with some mosfets that sometimes invert the pin value
    [EPD_1in9.cpp, internet_of_spores.ino, project_config.h]
2023-02-09 EPD_1in9: Add low battery message
    The datasheet indicates the display might be damaged by usage below 2.5V.
    Display a final "Lo Bat" message once the battery voltage drops to a
    critical level and then don't initialize the display after that.
    [EPD_1in9.cpp, internet_of_spores.ino, project_config.h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]
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2023-02-09 Battery Config: Sleep for maximal period when battery is critical
    When the battery falls below the critical voltage, sleep for the maximum
    ESP sleep time. Since ESP.deepSleepMax() doesn't work, I just determined
    a time by trial and error and subtracted 15%. In practice, this may not
    work across all temperatures or at low voltage (!), but we don't really
    intend to wake-up from this sleep anyway.
    [connectivity.cpp, internet_of_spores.ino, project_config.h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]
2023-02-09 EPD_1in9: Change RST pin to D8 to improve power consumption
    Note: Remove R9 from the Waveshare breakout board
    D8 is pulled low by ESP during deep sleep, which will keep the display
    in reset where it consumes virtually 0 μA (as close as I can measure).
    Other pins tend to float or go high during deep sleep, which resulted
    in measurable current draw for the display (~310 μA).
    While D8 seems to have the drive strength to fight against the 10k
    pull-up resistor on the Waveshare breakout board, this prevents the ESP
    from waking from deep sleep. This resistor would also result in some
    current draw during sleep if the pin was driven low.
    So, remove R9 from the Waveshare breakout board and use D8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
    [project_config.h]
2023-02-12 EPD_1in9: Create schematic for D1 mini adapter board
    [EPD_1in9.kicad_pcb, EPD_1in9.kicad_sch]
2023-02-17 EPD_1in9: Add custom footprint for CivLux CF3508
    [EPD_1in9.kicad_sch]
2023-02-17 EPD_1in9: Create board layout for D1 mini adapter board
    [EPD_1in9.kicad_pcb, EPD_1in9.kicad_sch]
2023-02-26 EPD_1in9: Add schematic symbol and footprint for the display outline
    [EPD_1in9.kicad_pcb, EPD_1in9.kicad_sch]
2023-03-05 EPD_1in9: Create 3D Model for Display
    Model is based on dimensions from https://www.waveshare.com/w/upload/5/53/1.9inch_Segment_e-Paper_Specification.pdf
    with some measured dimensions and most segment are roughly approximated.
    Workflow:
    -Open the .scad in FreeCAD
    -Wait a very long time...
    -Select final 2 groups from the imported geometry
    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
    [EPD_1in9.scad]
2023-03-05 EPD_1in9: Add 3D-model to display footprint
    KiCad treats .wrl models as being based on .1" units for historical
    reasons. Additionally, scaling and rotation in OpenSCAD result in loss of
    color information in the .csg.
    So, in the footprint properties, scaling for each axis is set to
    0.393700787 and a 90 degree rotation is needed.
    The translation of 49.35 mm brings it back in line with the KiCad origin.
    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
    [EPD_1in9.kicad_pcb]
2023-03-06 EPD_1in9: Add 3D-model for CF3527S connector
    IGES model downloaded from:
    https://www.cvilux.com/uploads/3d/101/681/CF35082D0RM_NH.zip
    Cleaned up colors in FreeCAD and exported as VRML.
    Also updated some of the footprint properties and renamed
    from CF35 to CF3527S.
    [EPD_1in9.kicad_pcb, EPD_1in9.kicad_sch]
2023-03-06 EPD_1in9: Move the EPD 3D-model into the kicad directory
    [EPD_1in9.kicad_pcb]
2023-03-11 EPD_1in9: Create Rev C circuit board
    Updates based on assembly of Rev A boards
    -Add labels for the D1-mini pin headers
    -Change pin-headers from THT to SMD
    (Note: the 2 pin horizontal connector doesn't have a proper 3D-model)
    -Remove large tracks from 3V3 and GND pads and enable thermal reliefs in
    the filled zones
    -Update display footprint to better show where the cable folds on the fab
    layer (this also matches the 3D-model)
    -Move FPC connector based on where the cable folds to (this also matches
    the 3D-model of the screen better)
    -Increase size of routed slot at bottom of board slightly
    -Add keepout zone around the HV nets
    [EPD_1in9.kicad_pcb, EPD_1in9.kicad_sch]
2023-03-14 EPD_1in9: Create Rev D circuit board
    Just switch from right-angle power input header to normal vertical header.
    [EPD_1in9.kicad_pcb, EPD_1in9.kicad_sch]
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2023-12-20 doc: fix drawing frame in initialization sequence diagram
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
